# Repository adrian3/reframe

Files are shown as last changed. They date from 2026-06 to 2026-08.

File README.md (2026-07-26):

# reFrame – the ePaper camera

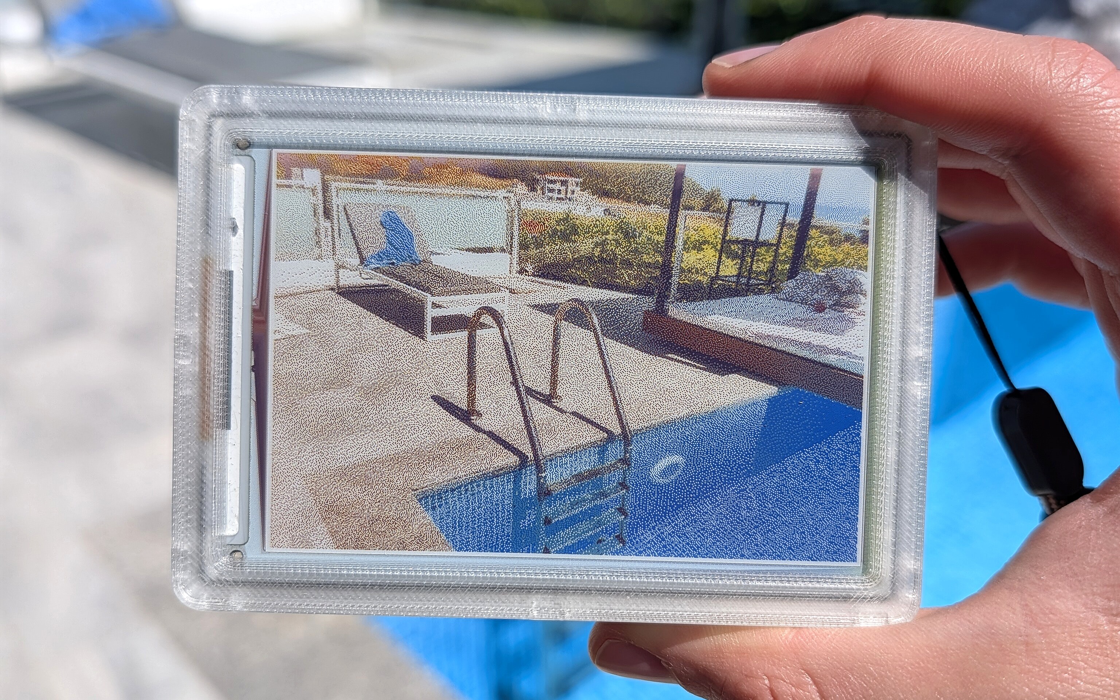
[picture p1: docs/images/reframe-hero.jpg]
reFrame ePaper camera in hand


reFrame is an experimental digital camera designed to capture and display one photo at a time.

reFrame uses a 6-color ePaper display, giving each photo a distinctive dithered texture. After you press the shutter, the display takes about 20 seconds to refresh — colors cycle through as electrical charges physically move ink particles into place, like a digital polaroid.

The photo stays on screen even after powering off. The only way to clear it is to take a new one. When not in use, reFrame doubles as a desk photo frame.

🌐 **[reframe.camera](https://reframe.camera)**

<p align="left">
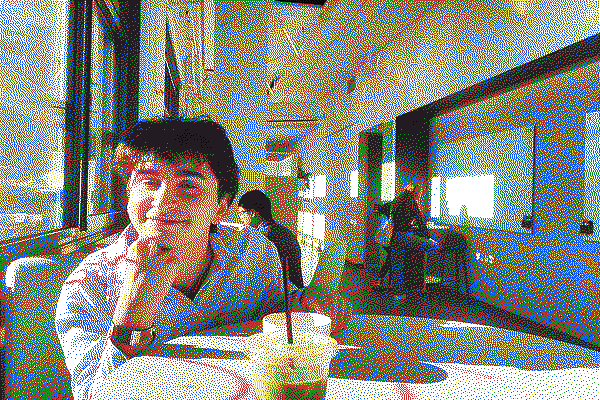
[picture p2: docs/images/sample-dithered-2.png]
Dithered photo sample
  
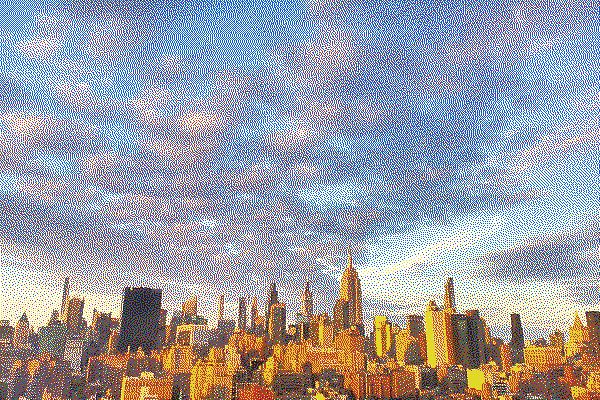
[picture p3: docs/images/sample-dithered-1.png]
Dithered photo sample
  
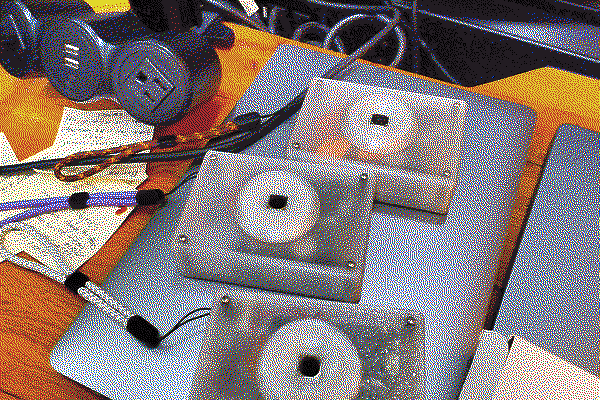
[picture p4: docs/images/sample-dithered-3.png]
Dithered photo sample
  
</p>

## What's Inside

The open source version of reFrame uses only off-the-shelf components so anyone can build their own.

| Component | Part |
|---|---|
| Computer | [Raspberry Pi Zero 2 W](https://www.pishop.us/product/raspberry-pi-zero-2w-with-headers/) |
| Camera | [Raspberry Pi Camera Module 3](https://www.digikey.com/en/products/detail/raspberry-pi/SC1223/17278639) |
| Display | [Waveshare 4" ePaper Spectra 6](https://www.waveshare.com/4inch-e-paper-hat-plus-e.htm) |
| Battery | [PiSugar 3](https://www.pisugar.com/products/pisugar-3-raspberry-pi-zero-battery) |
| Enclosure | 3D printed PLA |

See the full [bill of materials](docs/build-guide.md#materials).

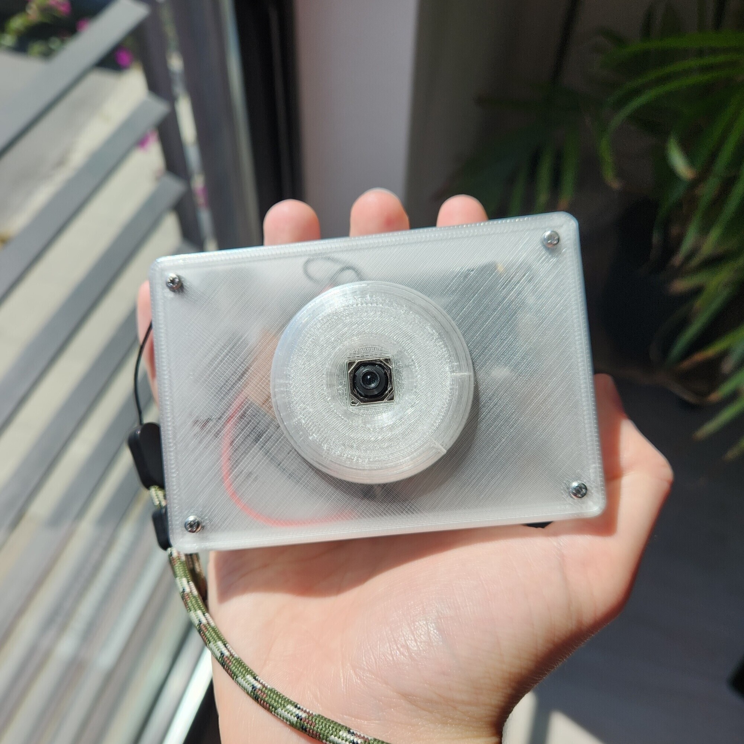
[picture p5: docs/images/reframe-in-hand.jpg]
reFrame ePaper camera in hand


## Getting Started

**→ [Build Guide](docs/build-guide.md)** — How to assemble the camera hardware

**→ [Software Setup](docs/software-setup.md)** — How to install and configure the software on your Pi

**→ [Hardware Porting Notes](docs/hardware-porting.md)** — How to adapt the code for other e-ink displays, cameras, or buttons

**→ [Dashboard Extensions](docs/dashboard-extensions.md)** — Upload your photos directly from the camera to Are.na + more.

Once you have the hardware assembled and Raspberry Pi OS flashed, run:

```bash
sudo apt update
sudo apt install -y git
git clone https://github.com/kaloyaan/reframe.git
cd reframe
chmod +x install.sh
./install.sh
```

## Using the Camera

  reFrame ePaper camera in action

reFrame is extremely minimalist by design. It has only a single button; no viewfinder, flash or zoom.

1. Press the combined power + shutter button to wake the camera and take a photo.
2. The original image is saved, then dithered to a 6-color palette to match the screen. The processed image is sent to the ePaper display.
3. The ePaper screen takes about 20 seconds to display the photo.
4. Press the button again to take a new photo. It'll replace the previous one on the display.
5. When you turn the camera off, the last photo will stay on the screen.

A web dashboard, accessible over the local network, lets you browse photos, download originals, change the displayed image, adjust camera settings, and optionally upload dithered photos to Are.na.

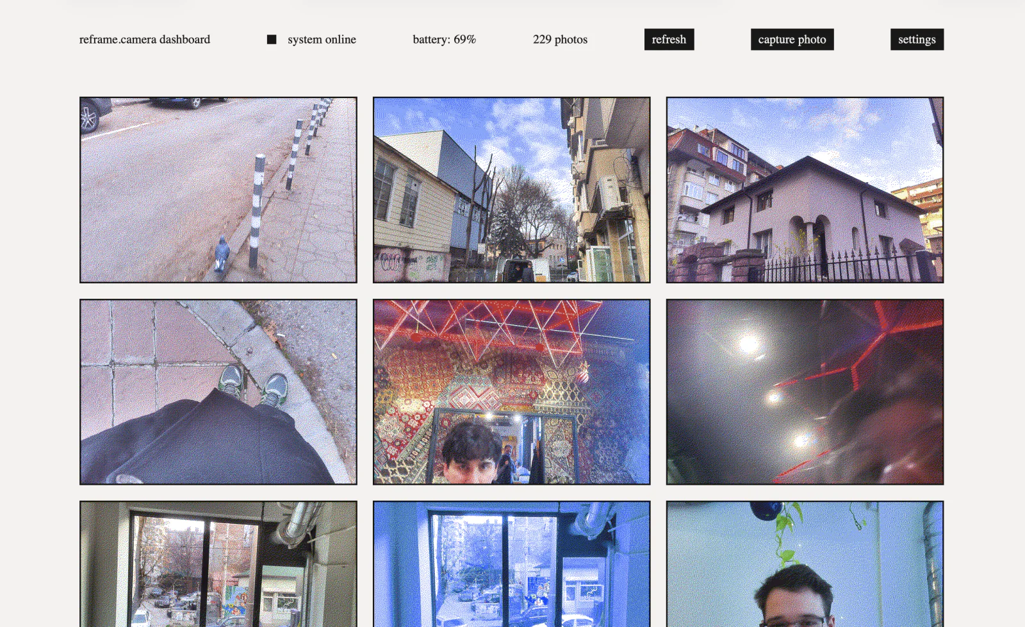
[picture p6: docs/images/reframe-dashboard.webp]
reFrame dashboard showing the photo gallery and camera controls


## Repository Structure

```
reframe/
├── reframe.py                 # main camera application
├── dashboard.py               # web dashboard for photo management
├── dashboard_proxy.py         # local port 80 dashboard proxy
├── install.sh                 # one-command setup script
├── settings.example.json      # default configuration
├── scripts/                   # hardware and privileged system helpers
│   ├── enable_hdr.sh
│   ├── reframe-apply-update
│   └── reframe-rtc-sync
├── systemd/                   # camera, dashboard, and RTC service units
│   ├── reframe.service
│   ├── reframe-dashboard.service
│   ├── reframe-dashboard-proxy.service
│   ├── reframe-rtc-restore.service
│   └── reframe-rtc-update.service
├── waveshare_epd/             # e-ink display drivers
├── hardware/                  # 3D-printable enclosure files
└── docs/                      # build guide & software setup
    ├── build-guide.md
    ├── software-setup.md
    ├── hardware-porting.md
    ├── dashboard-extensions.md
    └── images/
```

## License

Software in this repository is licensed under the [Apache License 2.0](LICENSE), unless a file says otherwise.

Hardware design files in [hardware/](hardware/) are licensed under [CC BY 4.0](hardware/LICENSE.md).

The build guide and documentation are provided for reuse with attribution where original to this project. Photos may include third-party products, packaging, logos, or trademarks, which are not licensed by this project.

The reFrame name, logo, domain, and branding are reserved.

## Credits

reFrame is made by [Kaloyan Kolev](https://kaloyankolev.com) with help from lots of friends and family. It started as a thesis prototype at Yale under the name eink.cam.

Thank you to [APOSSIBLE](https://apossible.com) for their generous support of this project.

reFrame logo + branding by [Kevin Chen](https://kevinnchen.com/).

More updates on [Instagram](https://instagram.com/reframe.camera).

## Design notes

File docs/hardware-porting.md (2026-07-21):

# Hardware Porting Notes

reFrame is intentionally small and mostly contained in `reframe.py`. If you want to use a different camera, display, or button, you can keep the same high-level logic and swap the hardware-specific adapter code.

## Display

The default display adapter is `EInkDisplay` in `reframe.py`, using the bundled Waveshare `epd4in0e` driver.

To port another e-ink display:

- Update `DISPLAY_IMAGE_WIDTH`, `DISPLAY_IMAGE_HEIGHT`, `DISPLAY_PANEL_WIDTH`, and `DISPLAY_PANEL_HEIGHT`.
- Update the palettes and hardware color mapping in `ImageProcessor`.
- Keep `EInkDisplay`'s public methods compatible: `prepare_async`, `is_busy`, `display_image`, `display_buffer`, `display_buffer_async`, `display_photo_by_id`, `clear_display`, `display_dashboard_qr`, and `sleep`.

You can find similar E Ink Spectra 6 displays from other brands like Pimoroni, GooDisplay, etc.

## Camera

The default camera adapter is `CameraManager`, backed by Picamera2 and Raspberry Pi Camera Module 3.

To port another camera:

- Keep `capture_image_with_metadata()` returning `(result_dict, PIL_image)`.
- Make `capture_image()` return a PIL `RGB` image.
- Keep `configure_camera()`, `reload_settings()`, and `apply_camera_settings()` present, even if some settings become no-ops.
- Update or remove `scripts/enable_hdr.sh` and the `_enable_camera_hdr()` startup call in `reframe.py` if your camera does not use Camera Module 3 HDR.
- Update `settings.example.json` camera defaults for the resolution and controls your camera supports.

## Button And Power

The default button path reads PiSugar 3 over I2C in `main()`. To port another trigger:

- Replace `is_power_button_pressed()` in `main()`.
- Keep the short-press behavior calling `camera_system.capture_photo_api()`.
- Keep long-press shutdown behavior in the power manager if your hardware has one; otherwise implement it explicitly.

## Dashboard

The dashboard talks to the hardware service through the API routes in `reframe.py`. If the adapter methods above remain compatible, the dashboard should not need display- or camera-specific changes.

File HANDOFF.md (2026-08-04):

# reFrame Camera — Setup Handoff

Context for picking up this project. The working repo is at `~/Desktop/reframe` (cloned from https://github.com/kaloyaan/reframe, now diverged from upstream — see changes below).

## Build deviation from stock instructions

This build powers the Raspberry Pi Zero 2 W directly (plain USB/battery power) instead of through a PiSugar 3 board. That removes PiSugar's hardware power-on, hardware long-press shutdown, and battery monitoring. To compensate, a physical momentary push button was wired directly to the Pi's GPIO for photo capture:

- Button leg 1 → **GPIO4** (physical pin 7 on the 40-pin header)
- Button leg 2 → **GND** (physical pin 9, adjacent to pin 7)
- No external resistor — code enables the Pi's internal pull-up, so idle = HIGH, pressed = LOW.

Optional shutdown warning buzzer:

- Buzzer `+` / signal → **GPIO23** (physical pin 16)
- Buzzer `-` / GND → **GND** (physical pin 14 is nearby)
- Current settings use the buzzer for a shutter click on capture, a warning one minute before the 10-minute inactivity shutdown, and a shutdown cadence before long-press or inactivity shutdown.
- Use a small active 3.3V buzzer or a low-current piezo. If the buzzer draws more than a few milliamps, drive it with a transistor instead of directly from the GPIO pin.

## Code changes already made (local repo, not pushed upstream)

**`reframe.py`** — in `main()`, the PiSugar I2C button-read block was replaced with a direct GPIO read:
- Removed: `smbus2` I2C read from PiSugar register `0x02` at address `0x57`.
- Added: `gpiozero.Button(4, pull_up=True, bounce_time=0.02)`, with `is_power_button_pressed()` now just returning `shutter_button.is_pressed`.
- The existing short-press (capture) / long-press (ignore) polling loop below it was untouched — it only calls `is_power_button_pressed()`, so no other logic needed to change.
- `finally: bus.close()` → `finally: shutter_button.close()`.
- `gpiozero` needed no new dependency — it's already used by `waveshare_epd/epdconfig.py` for the display, so it's present on the Pi already.

**`install.sh`** — Step 3 ("PiSugar Power Manager") was replaced with a no-op that just logs a warning and skips it, since there's no PiSugar hardware to detect. Everything else in the script (system packages, SPI/I2C enable via `raspi-config`, boot-speed trims, systemd services, user groups) is unmodified and still needed — SPI is still required for the e-ink display, and the `gpio` group (already added by `usermod` in the script) covers permission for GPIO4.

**Camera/display processing** — this build is currently configured for Raspberry Pi Camera Module V2 / NoIR V2 (`imx219`):
- Boot config should use `camera_auto_detect=0` and `dtoverlay=imx219`.
- Capture defaults are `3280×2464`, the full Camera Module V2 still resolution.
- Original JPEGs are saved at full capture resolution.
- The dithered display image keeps the full `2464px` source height, center-crops width to about `1643px`, resizes that portrait crop to `400×600`, then rotates it `-90°` to the final `600×400` dithered image. This loses more width than the previous landscape crop but preserves full height.

Nothing else in the codebase hard-depends on PiSugar: `dashboard.py`'s `/api/battery` endpoint calls `nc` to `127.0.0.1:8423` and gracefully returns `battery_level: None` if `pisugar-server` isn't running (dashboard just shows `--%`), and `reframe.service` has no `Requires=`/`After=` on `pisugar-server.service`.

## Current status

SD card is flashed (Raspberry Pi OS Lite, hostname `reframe`, user `cam`), the Pi is wired up with the camera, e-ink display, and the direct GPIO button, and it was booting for the first time as of this handoff. SSH has not yet been used to install the software on the Pi itself — the local repo on the Mac has the code changes above, but that code has not yet been transferred to the Pi.

## Remaining steps

Run from the user's own Mac terminal (an assistant needs actual local-network/SSH access to the Pi to do this — a sandboxed environment without LAN access cannot reach `reframe.local`):

```bash
# 1. SSH in (password is whatever was set in Raspberry Pi Imager)
ssh cam@reframe.local

# 2. From a separate terminal window (not the SSH session), copy the
#    locally-modified repo to the Pi — do NOT git clone from GitHub,
#    that would pull the vanilla version without the GPIO button change
rsync -av --exclude='.git' ~/Desktop/reframe/ cam@reframe.local:~/reframe/

# 3. Back in the SSH session, install
cd ~/reframe
chmod +x install.sh
./install.sh
# It will print that it's skipping PiSugar, then proceed normally.
# Say yes when it prompts to reboot.
```

After reboot, verify:

```bash
# Watch for capture events while pressing the button
sudo journalctl -u reframe.service -f
# Should log "Short press detected... capturing photo" on press

# If the button seems unresponsive, sanity-check the pin directly
python3 -c "from gpiozero import Button; b=Button(4); print('press now...'); [print(b.is_pressed) for _ in range(100)]"
# Should print True while held
```

Dashboard: `http://reframe.local` (fallback `http://reframe.local:8000`). Battery will show `--%` since there's no PiSugar — expected.

## WiFi priority

The live Pi is using NetworkManager. It has two WiFi profiles:

- `iphone-hotspot` — SSID `Ade’s iPhone 17 Pro`, autoconnect priority `100`
- `netplan-wlan0-Area53` — home WiFi fallback, autoconnect priority `10`

The hotspot password is stored only in NetworkManager on the Pi, not in this repo. A boot helper, `reframe-prefer-phone-wifi.service`, scans for several minutes after networking starts and switches to `iphone-hotspot` if the phone SSID is visible; otherwise it leaves Area53 or any other current connection alone.

On a fresh SD card, add the phone network with:

```bash
sudo nmcli connection add type wifi ifname wlan0 con-name iphone-hotspot ssid "Ade’s iPhone 17 Pro"
sudo nmcli connection modify iphone-hotspot \
  connection.autoconnect yes \
  connection.autoconnect-priority 100 \
  connection.autoconnect-retries -1 \
  wifi-sec.key-mgmt wpa-psk \
  wifi-sec.psk "<iphone hotspot password>"
sudo nmcli connection modify netplan-wlan0-Area53 \
  connection.autoconnect yes \
  connection.autoconnect-priority 10 \
  connection.autoconnect-retries -1
sudo systemctl enable reframe-prefer-phone-wifi.service
```

On the iPhone, keep **Personal Hotspot → Allow Others to Join** enabled when using the camera outside. If the Pi does not see the hotspot, enable **Maximize Compatibility** so the hotspot is available in a Pi Zero-friendly 2.4 GHz mode.

If the Pi still does not see the hotspot, unlock the iPhone and leave **Settings → Personal Hotspot** open while powering on the camera. iPhones sometimes stop advertising the hotspot aggressively when no device is connected.

## Known non-issue

Long-press-to-shutdown is implemented in software: hold the GPIO4 shutter button for at least 2 seconds, release, and reFrame plays the shutdown cadence on GPIO23 before running `sudo shutdown -h now`. The 10-minute inactivity auto-shutdown also remains enabled. After shutdown, powering the camera back on still means unplugging/replugging power because this direct-power build has no PiSugar-style hardware wake circuit.

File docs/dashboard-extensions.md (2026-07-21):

# Dashboard Upload Extensions

Dashboard extensions add extra per-photo action buttons in the web dashboard. They are server-side only, off by default, and configured through `settings.json` via the dashboard settings modal.

The first built-in extension is photo upload to an [Are.na](https://www.are.na/) channel.

## How Extensions Work

Extensions live in `dashboard.py` and are registered in `extension_registry`.

Each extension should provide:

- `id`: stable machine id used in settings and API paths
- `label`: human-readable name
- `action_label`: text shown on the photo action button
- `requires_dithered`: whether the action should only appear for photos with a dithered file
- `enabled(settings)`: whether the extension is enabled
- `configured(settings)`: whether all required settings are present
- `run(photo, settings)`: async server-side action

The browser doesn't receive secrets, it only asks:

```http
GET /api/extensions/actions
```

That returns safe action metadata for configured extensions. When a user taps an extension button, the dashboard calls:

```http
POST /api/extensions/{extension_id}/photos/{photo_id}
```

The dashboard server loads the photo metadata, reads private settings, and runs the extension.

For v1, extensions are not loaded dynamically from arbitrary folders. To add one, subclass `DashboardExtension` in `dashboard.py` and register it in `ExtensionRegistry([...])`.

## Settings Shape

Extension settings are stored under `extensions`:

```json
{
  "extensions": {
    "arena": {
      "enabled": false,
      "channel": "",
      "access_token": ""
    }
  }
}
```

Tokens are write-only in the dashboard API:

- `GET /api/settings` returns `access_token: ""`
- `GET /api/settings` also returns `access_token_configured: true` when a saved token exists
- saving settings with a blank token preserves the saved token
- entering a new token replaces the saved token
- using the clear-token control sets `access_token_clear: true` and removes the saved token

This avoids accidentally exposing tokens to the browser UI, but the dashboard is still trusted-LAN software. Do not expose it directly to the public internet.

## Are.na Upload

The Are.na extension uploads the dithered PNG version of a photo to a configured Are.na channel.

Example Are.na channel: [Shot on reFrame](https://www.are.na/kalo/shot-on-reframe).

### Setup

1. Create an Are.na channel.
2. Create an Are.na API access token with write access.
3. Open the reFrame dashboard.
4. Open settings.
5. Under `extensions`, set `are.na upload` to `enabled`.
6. Enter the channel slug or numeric id.
7. Paste the access token and save settings.

When the extension is fully configured, an `are.na` button appears next to photo actions for photos that have a dithered PNG.

### What Gets Uploaded

Only the dithered PNG is uploaded. Original JPEGs are not uploaded by this extension.

If the advanced 2× dithered export setting is enabled, the dashboard enlarges the PNG with nearest-neighbor scaling immediately before upload. It does not crop or modify the stored dithered photo. The setting is disabled by default.

The created Are.na block uses:

- title: `reFrame {photo_id}`
- description:

```text
Dithered photo shot on [reframe.camera](https://reframe.camera)

Captured on {timestamp}
```

If `system.camera_name` is set in dashboard settings, the captured line appends `by {camera_name}`.

- metadata:

```json
{
  "source": "reframe",
  "photo_id": "{photo_id}"
}
```

## Adding Another Extension

Add a new class in `dashboard.py`:

```python
class ExampleExtension(DashboardExtension):
    id = "example"
    label = "Example"
    action_label = "example"
    requires_dithered = True

    def configured(self, settings):
        extension_settings = self.get_settings(settings)
        return self.enabled(settings) and bool(extension_settings.get("api_key"))

    async def run(self, photo, settings):
        dithered_path = photo.get("dithered_path")
        if not dithered_path:
            raise HTTPException(status_code=400, detail="This photo does not have a dithered version")
        # Upload or process the file here.
        return {
            "status": "success",
            "message": "Uploaded photo",
            "extension": self.id
        }
```

Then register it:

```python
extension_registry = ExtensionRegistry([
    ArenaExtension(),
    ExampleExtension(),
])
```

Add its settings defaults to `SettingsManager.default_settings`, `settings.example.json`, and the dashboard settings UI. If the extension has a secret, mirror the Are.na write-only token behavior.

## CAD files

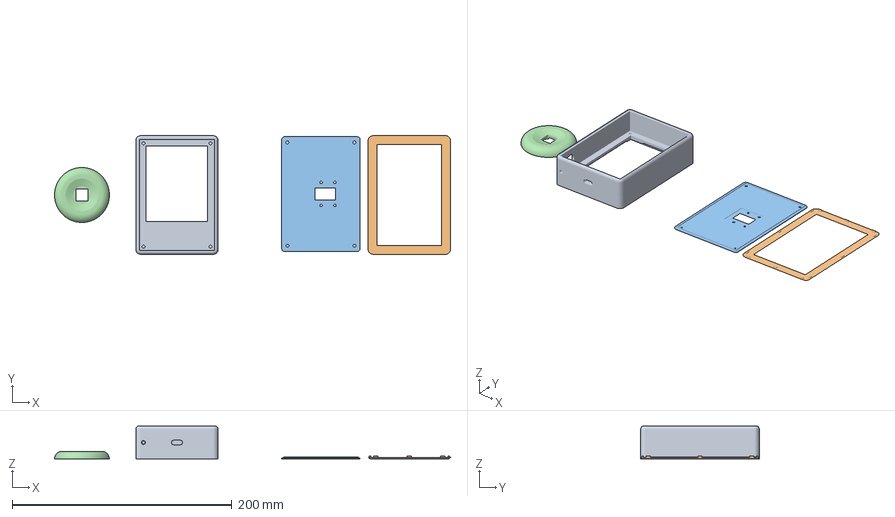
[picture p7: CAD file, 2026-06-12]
hardware/reframe-3dprint.3mf
360.5 x 108.0 x 30.0 mm
enclosure 10.stl
bezel 8.stl
lid 8.stl
ring 9.stl

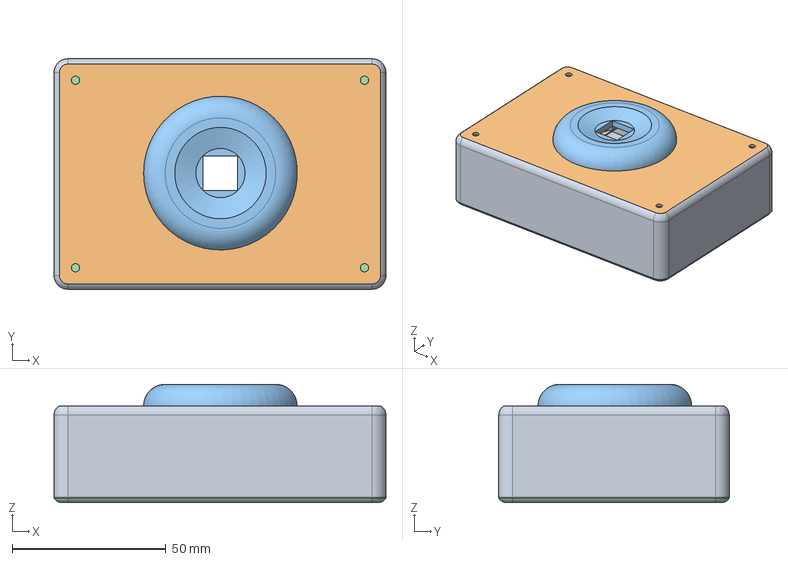
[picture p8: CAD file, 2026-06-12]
hardware/reframe.step
108.0 x 75.0 x 38.5 mm

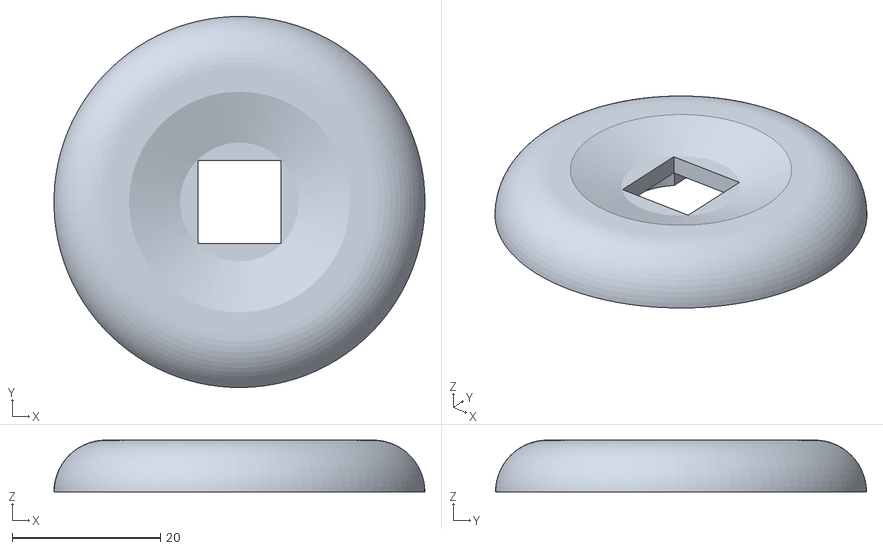
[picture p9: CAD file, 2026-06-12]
hardware/ring.stl
50.0 x 50.0 x 7.00

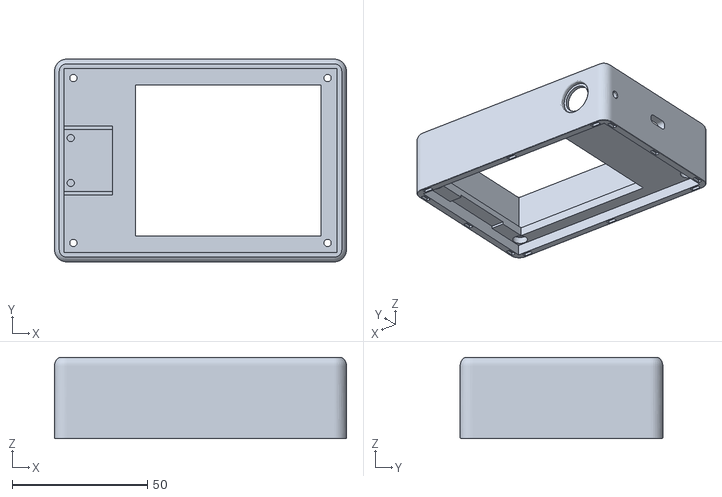
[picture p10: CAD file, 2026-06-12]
hardware/enclosure.stl
108.0 x 75.0 x 30.0

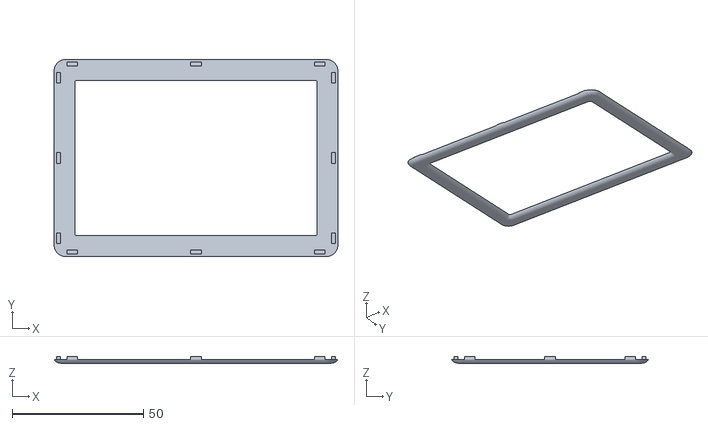
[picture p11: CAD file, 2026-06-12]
hardware/bezel.stl
108.0 x 75.0 x 2.50

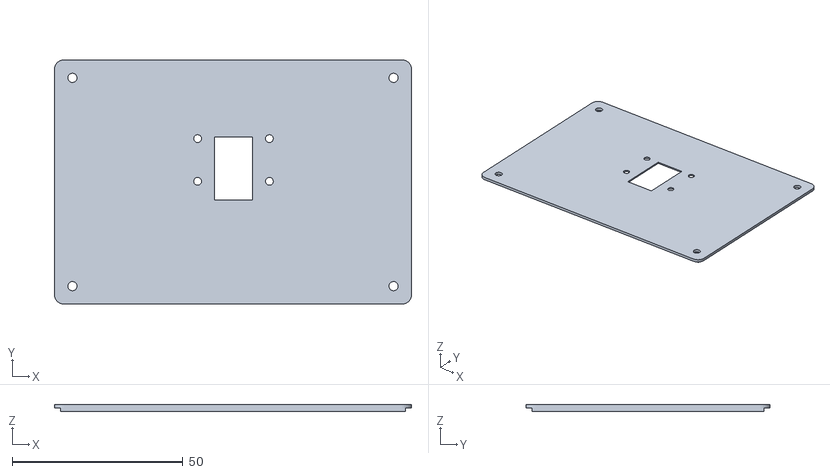
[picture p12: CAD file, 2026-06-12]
hardware/lid.stl
104.5 x 71.5 x 2.00

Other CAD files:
hardware/reframe.f3d

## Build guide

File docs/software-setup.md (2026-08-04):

# Software Setup

How to set up a reFrame camera from scratch.

## 1. Flash the SD Card

Download and install [Raspberry Pi Imager](https://www.raspberrypi.com/software/). Insert a microSD card into your computer and flash it with the following settings:

- **Device**: Raspberry Pi Zero 2 W
- **OS:** Raspberry Pi OS (other) > Raspberry Pi OS Lite (64-bit)
- **Hostname:** `reframe`
- **Username:** `cam`
- **Password:** your choice (but write it down somewhere safe)
- **WiFi:** enter your home network name and password. If you want to use the camera on the go, also add your phone's hotspot (you can add multiple networks)
- **Services:** Enable SSH with password authentication

Eject the card, insert it into the Pi Zero 2 W, and power it on. On a new
PiSugar 3, the first power-on may require a short press followed by a long
press. The reFrame installer disables this accidental-touch prevention mode so
later power-ons use a single press.

## 2. SSH into the Pi

Once the Pi has booted (give it a minute), connect from your computer:

```bash
ssh cam@reframe.local
```

Enter the password you set in the imager.

## 3. Install reFrame

```bash
sudo apt update
sudo apt install -y git
git clone https://github.com/kaloyaan/reframe.git
cd reframe
chmod +x install.sh
./install.sh
```

If the official PiSugar installer asks you to select a model, choose **PiSugar 3**. After installation:

- `pisugar-server` runs as a systemd service and starts on boot
- Battery level is available via TCP on port `8423` (the dashboard reads this automatically)
- Power management web UI is at `http://reframe.local:8421`

By default, PiSugar 3 ships with accidental-touch prevention enabled. In that mode, power-on requires a short press followed by a long press. reFrame disables that mode during installation so the camera behaves like this:

- **single press while off** = power on
- **startup** = automatically take and display one photo
- **single press while on** = take a new photo
- **long press while on** = shut down
- **10 minutes of inactivity** = automatic shutdown to prevent battery drain

The installer applies this with the PiSugar Power Manager command `set_anti_mistouch false`. If you installed PiSugar after running `install.sh`, run the reFrame installer again, or apply the setting manually:

```bash
echo "set_anti_mistouch false" | nc -q 0 127.0.0.1 8423
```

You can check the current setting with:

```bash
echo "get anti_mistouch" | nc -q 0 127.0.0.1 8423
```

> **Note:** reFrame reads the button directly via I2C (address `0x57`) for photo capture. PiSugar still handles battery monitoring, one-press power-on, and long-press shutdown.

### PiSugar RTC

The installer keeps the Raspberry Pi system clock and the PiSugar 3 real-time clock in UTC. reFrame synchronizes them automatically on startup: it syncs the system clock from the RTC, and whenever network time becomes available it updates both clocks.

## 4. Reboot

```bash
sudo reboot
```

After rebooting, reFrame starts automatically. The camera takes a photo on startup, sends it to the ePaper screen, then saves the original JPEG and dithered PNG in the background.

### Troubleshooting / Verifying the Installation

If something is not working, SSH back into the camera after it finishes booting, then check that all three services are active:

```bash
sudo systemctl is-active \
    reframe.service \
    reframe-dashboard.service \
    reframe-dashboard-proxy.service
```

Each line should say `active`. Confirm that the services select the managed
Python environment:

```bash
/home/cam/reframe/scripts/reframe-python -c \
    'import sys; print(sys.executable)'
```

The result should be `/home/cam/reframe/.venv/bin/python`. Finally, test both
dashboard paths from the camera itself:

```bash
wget -q --spider http://127.0.0.1:8000/ && echo "dashboard backend OK"
wget -q --spider http://127.0.0.1/ && echo "dashboard proxy OK"
```

---

## Dashboard

reFrame dashboard showing the photo gallery and camera controls

Open a browser on any device connected to the same network:

```
http://reframe.local
```

The dashboard lets you browse photos, download originals, change the displayed image, and adjust camera settings.

The dashboard also remains available on port 8000 as a fallback:

```
http://reframe.local:8000
```

If you used a different Pi hostname during Raspberry Pi Imager setup, replace `reframe` with that hostname.

Dashboard settings include a software update button for git-based installs. It checks the configured upstream repo, installs fast-forward updates only, preserves ignored user data such as your settings and photos, refreshes dependencies and service files, and asks you to reboot after a successful update.

Advanced export settings include an optional 2× dithered-image mode. When enabled, dithered downloads and Are.na uploads are enlarged at export time to help them look sharp on social media. Original photos, stored dithered photos, gallery previews, display output, and download-all ZIP files are unchanged. This option is disabled by default.

### Using with a Phone Hotspot

To use the camera without a WiFi network, enable your phone's hotspot. As long as you added the hotspot name and password during flashing (step 1), the Pi will connect to it automatically on boot.

On iPhone, you can find your hotspot name under Settings → General → About → Name. Enable **Maximize Compatibility** in hotspot settings for the Pi to connect reliably.

Whenever the camera connects or reconnects to WiFi, it shows a dashboard QR code on the ePaper display. The network watcher remains active after startup, and the QR encodes the numeric IP when one is available so it also works on hotspots that do not resolve `.local` hostnames. This behavior is enabled by default and can be disabled under system settings in the dashboard.

On Android/Pixel hotspots, `.local` hostnames may not resolve reliably. In that case, use the QR code's numeric IP URL, for example `http://192.168.x.x`.

## HDR (Camera Module 3)

HDR is automatically enabled at startup via `scripts/enable_hdr.sh` after Python imports finish but before Picamera2 opens the camera. This overlaps camera-device discovery with Python startup. To control it manually:

```bash
# Enable
v4l2-ctl --set-ctrl wide_dynamic_range=1 -d /dev/v4l-subdev0

# Disable
v4l2-ctl --set-ctrl wide_dynamic_range=0 -d /dev/v4l-subdev0
```

HDR + autofocus make a big difference on the ePaper display.

## Photo Formats And Capture Flow

reFrame captures the startup/button photo into memory first so the image can be dithered and sent to the ePaper display quickly. It then saves files in the background:

- Original camera captures are saved as JPEGs at the configured camera resolution. For the local Camera Module V2 build, the default is the full `3280×2464` still frame.
- The display/dashboard dithered version is saved as a `600×400` PNG so the 6-color dithered image stays crisp.
- To make the `3280×2464` camera frame fit the display without distortion, reFrame keeps the full `2464px` source height, center-crops width to about `1643px`, resizes that portrait crop to `400×600`, then rotates it `-90°` to the final `600×400` dithered image.
- Immediately after a capture, the dashboard may take a moment to show the newest files while the background save finishes.

By default, reFrame shuts down automatically after 10 minutes without button, dashboard, or display activity to avoid draining the PiSugar battery. You can change this in `settings.json` with `system.auto_timeout_minutes` and `system.auto_timeout_enabled`.

## Other Displays Or Cameras

The reference build uses Raspberry Pi Camera Module 3, PiSugar 3, and a Waveshare 4" Spectra 6 ePaper HAT, but the hardware-specific code is intentionally isolated in `CameraManager`, `EInkDisplay`, and the small button block in `reframe.py`.

See [Hardware Porting Notes](hardware-porting.md) for adapting the repo for Pimoroni, Good Display, another camera module, or a different button/power board.

## Upload Extensions

The dashboard can show optional per-photo upload buttons. Extensions are off by default and run on the dashboard server so API tokens are not sent back to the browser.

The built-in Are.na extension uploads the dithered PNG of a photo. Enable it from dashboard settings by entering an Are.na channel slug/id and an access token with write access. The token field is write-only: leave it blank to keep the saved token, enter a new token to replace it, or use the clear-token button to remove it.

Example Are.na channel: [Shot on reFrame](https://www.are.na/kalo/shot-on-reframe).

See [Dashboard Extensions](dashboard-extensions.md) for the full Are.na flow and notes on adding your own upload extension.

## Service Commands

```bash
sudo systemctl status reframe.service      # check status
sudo journalctl -u reframe.service -f      # view logs
sudo systemctl restart reframe.service     # restart
sudo systemctl stop reframe.service        # stop

sudo systemctl status reframe-dashboard.service       # dashboard backend
sudo journalctl -u reframe-dashboard.service -f       # dashboard logs
sudo systemctl restart reframe-dashboard.service      # restart dashboard
```

---

## Manual Install

If you prefer to set things up by hand, here's what the install script does:

### System Packages

```bash
sudo apt update
sudo apt install -y git python3-pip python3-venv python3-picamera2 python3-spidev \
    python3-gpiozero v4l-utils i2c-tools netcat-openbsd wget
```

### PiSugar Power Manager

```bash
wget https://cdn.pisugar.com/release/pisugar-power-manager.sh
bash pisugar-power-manager.sh -c release
echo "set_anti_mistouch false" | nc -q 0 127.0.0.1 8423
```

Select **PiSugar 3** if prompted by the PiSugar installer.

### Python Packages

```bash
python3 -m venv --system-site-packages .venv
PYTHONNOUSERSITE=1 .venv/bin/python -m pip install -r requirements.txt
```

`--system-site-packages` makes the Raspberry Pi OS Picamera2/libcamera packages
available inside the project environment. `PYTHONNOUSERSITE=1` keeps the
environment reproducible if setup is rerun or the camera is upgraded by
preventing unrelated packages in `~/.local` from taking precedence. A fresh
installation does not need any special cleanup. Do not delete the operating
system's `EXTERNALLY-MANAGED` marker or globally enable
`--break-system-packages`.

### Enable Hardware Interfaces

```bash
sudo raspi-config nonint do_i2c 0
sudo raspi-config nonint do_spi 0
```

This local build is configured for the Raspberry Pi Camera Module V2 / NoIR V2
(`imx219`). Use this boot config:

```bash
camera_auto_detect=0
dtoverlay=imx219
```

Boot config paths:
- **Bullseye:** `/boot/config.txt`
- **Bookworm:** `/boot/firmware/config.txt`

### User Permissions

```bash
sudo usermod -a -G video,i2c,spi,gpio cam
```

Log out and back in for changes to take effect.

### Configuration

```bash
cp settings.example.json settings.json
```

### Systemd Services

```bash
sudo cp systemd/reframe.service /etc/systemd/system/
sudo cp systemd/reframe-dashboard.service /etc/systemd/system/
sudo cp systemd/reframe-dashboard-proxy.service /etc/systemd/system/
sudo cp systemd/reframe-rtc-restore.service /etc/systemd/system/
sudo cp systemd/reframe-rtc-update.service /etc/systemd/system/
chmod +x scripts/enable_hdr.sh scripts/reframe-python
sudo install -o root -g root -m 0755 scripts/reframe-rtc-sync /usr/local/sbin/reframe-rtc-sync
sudo install -d -o root -g root -m 0755 /var/lib/reframe
sudo timedatectl set-timezone UTC
sudo timedatectl set-ntp true
sudo systemctl daemon-reload
sudo systemctl reenable reframe.service
sudo systemctl enable reframe-dashboard.service reframe-dashboard-proxy.service reframe-rtc-restore.service reframe-rtc-update.service
sudo reboot
```

### Boot-Speed Settings

The camera service selects the `ondemand` CPU governor when the host supports it. This lets capture and image processing use the Pi's full clock under load while returning to its lower idle clock between photos.

The installer optimizes for fastest boot-to-first-photo while keeping WiFi, SSH, mDNS, PiSugar, and camera capture working.

It writes these headless hardware settings to the Pi boot config.

```bash
dtoverlay=disable-bt
dtparam=audio=off
hdmi_blanking=2
boot_delay=0
camera_auto_detect=0
dtoverlay=imx219
display_auto_detect=0
disable_splash=1
disable_poe_fan=1
force_eeprom_read=0
enable_tvout=0
```

It also disables services and timers that are not needed for a headless camera:

```bash
sudo systemctl disable --now \
  ModemManager.service \
  triggerhappy.service triggerhappy.socket \
  udisks2.service rsync.service rpi-eeprom-update.service \
  networking.service keyboard-setup.service console-setup.service \
  rsyslog.service \
  bluetooth.service hciuart.service bluealsa.service \
  apt-daily.timer apt-daily-upgrade.timer man-db.timer \
  e2scrub_all.timer fstrim.timer
```

Do **not** disable these for the normal camera build:

```bash
ssh.service
wpa_supplicant.service
dhcpcd.service
avahi-daemon.service
pisugar-server.service
reframe.service
reframe-dashboard.service
reframe-dashboard-proxy.service
```

On the reference Pi Zero 2 W, these changes plus the in-memory capture path reduced app-level startup capture-to-display dispatch to under 1 second once Picamera2 is ready. A cold boot still includes OS, HDR, Python import, and libcamera startup time; the ePaper display refresh itself still takes about 20 seconds to physically finish, and that is expected.

To undo the service trims, re-enable only what you need, for example:

```bash
sudo systemctl enable --now bluetooth.service hciuart.service
```

---

## Troubleshooting

**Camera not detected**
- Verify the ribbon cable is seated properly on both ends
- Ensure `cam` is in the `video` group: `groups cam`

**Display not updating**
- Confirm SPI is enabled: `sudo raspi-config nonint get_spi` (should return `0`)
- Check physical connections between the display HAT and Pi header
- Review logs: `sudo journalctl -u reframe.service`

**Button not responding**
- Confirm I2C is enabled: `sudo raspi-config nonint get_i2c` (should return `0`)
- Check: `sudo i2cdetect -y 1` (should show a device at address `57` for PiSugar)

**Service won't start**
- The service files expect the repo at `/home/cam/reframe`
- Check: `sudo systemctl status reframe.service`
- View full logs: `sudo journalctl -u reframe.service --no-pager`

**Dashboard says it is starting or unavailable**
- Check the backend directly: `wget -S -O /dev/null http://127.0.0.1:8000/`
- Check its status: `sudo systemctl status reframe-dashboard.service --no-pager -l`
- View this boot's logs: `sudo journalctl -u reframe-dashboard.service -b --no-pager -n 100`
- Confirm the service interpreter exists: `test -x /home/cam/reframe/.venv/bin/python && echo OK`
- Re-run `./install.sh` if the virtual environment or dependencies are missing

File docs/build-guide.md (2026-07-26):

# Build Guide

Everything you need to build your own reFrame camera. This version intentionally uses only off-the-shelf components so it's easy to customize.

The build requires some 3D printing and soldering experience, so it's not necessarily for absolute beginners. If you need help with any part of the process, you can reach out via email or Instagram.

## Materials

Approximate cost: **~$200-250 USD per camera**

| # | Component | Part | ~Price | Link | Notes |
|---|---|---|---|---|---|
| 1 | Computer | Raspberry Pi Zero 2 WH | $20 | [PiShop.us](https://www.pishop.us/product/raspberry-pi-zero-2w-with-headers/) | WH version has pre-soldered headers for easier assembly. Non-header version works as well. |
| 2 | Camera | Raspberry Pi Camera Module 3 | $25 | [Digi-Key](https://www.digikey.com/en/products/detail/raspberry-pi/SC1223/17278639) | Standard field-of-view model. The Camera Module 3 is recommended because the autofocus and HDR make a big difference in image quality on the ePaper display. |
| 3 | Display | Waveshare 4" ePaper Spectra 6 (HAT+) | $50 | [Waveshare](https://www.waveshare.com/4inch-e-paper-hat-plus-e.htm?sku=27367) | Connects directly to the Pi's GPIO header — no additional wiring needed. The [driver](../waveshare_epd/) is bundled in this repo. |
| 4 | Battery | PiSugar 3 Battery Board | $40 | [PiSugar](https://www.pisugar.com/products/pisugar-3-raspberry-pi-zero-battery) or [Amazon](https://www.amazon.com/dp/B0FB3N1YSK) | Provides power and physical button interface. This build works only with PiSugar 3 because of how it handles on-off buttons. Requires [`pisugar-server`](https://github.com/PiSugar/PiSugar/wiki/PiSugar-Power-Manager-(Software)) for monitoring; the [Software Setup](software-setup.md) guide installs it. |
| 5 | Storage | 32 GB microSD card | $10 | Any brand, the faster, the better. | For OS and photo storage. |
| 6 | Push Button | 12mm Stainless Steel Push Button | $6 | [Amazon](https://www.amazon.com/dp/B0811QKG1R) | Used as a combined hardware on/off + shutter button. |
| 7 | Camera Cable | Short Pi ribbon cable | $6 | [Amazon](https://www.amazon.com/dp/B085RW9K13?th=1) | For neatness; can also use the one that comes with the camera. |
| 8 | Nylon Standoffs | M2.5 Hex Standoff Spacers Kit | $10 | [Amazon](https://www.amazon.com/COMRUN-M2-5-Standoff-Assortment-Motherboard/dp/B0CKBWQSNY/) | Hold the build together. The camera needs 4 20mm standofs; could be nylon or metal. |
| 9 | Metal Screws | M2.5 metal screws | $10 | [Amazon](https://www.amazon.com/dp/B01N5RDAUX) | Holds the front lid + the USB-C board. Could be metal or nylon (if you want to use the ones from the link above). I went with metal for a nicer look on the front lid.  |
| 10 | Camera Screws | M2 screws | $7 | [Amazon](https://www.amazon.com/QOOSIKICC-Assortment-Washers-Machine-Assorted/dp/B0DDY2L533/) | For mounting the camera module to the enclosure. |
| 11 | USB C Port | USB C Breakout Board | $8 | [Amazon](https://www.amazon.com/Breakout-Connector-Serial-Female-Adapter/dp/B0F2S1K5X8) | Used for external USB-C port access. |
| 12 | Connectors | JST 1.25mm 2-Pin Micro Connectors | $7 | [Amazon](https://www.amazon.com/dp/B013JRWCBU) | So it's easier to connect the USB-C port + power button during assembly. |
| 13 | Filament | Transparent PLA Filament | $20 | [Amazon](https://www.amazon.com/dp/B08VRM8KZJ) | Good for reliable overhangs and fine details (PETG could also work but is more finicky). Translucent so status lights are visible under the board. The one used in my build is the GIANTARM Clear PLA Filament. |
| 14 | Wrist Strap | Wrist strap | $6 | [Amazon](https://www.amazon.com/dp/B0BC8G4ZR2) | Hand strap for carrying. |
| 15 | Putty | Sticky putty | $4 | Any brand | For holding the battery securely in place. |
| 16 | Carry Case | Optional carry case | $12 | [Amazon](https://www.amazon.com/dp/B0DBLMKYGB) | For travel protection. This size (5.5" × 3.7" × 2.8") fits the camera well. |
| 17 | Charging Cable | USB-A to USB-C | - | - | For charging the camera. C-to-C cables might not work unless you solder some extra ports on the USB-C board. |

## Enclosure

The 3D-printable files for the camera case are located in the [hardware/](../hardware/) directory. The model consists of four separate parts:

- **[enclosure.stl](../hardware/enclosure.stl)**: The main body that holds the Pi, battery, and display. It has cutouts for the display, the USB-C port, the power/shutter button, and the wrist strap.
- **[lid.stl](../hardware/lid.stl)**: The back cover of the camera. It attaches to the main enclosure using 4x M2.5 screws that screw into the standoffs integrated into the main enclosure.
- **[bezel.stl](../hardware/bezel.stl)**: The front bezel that frames the ePaper display. It attaches to the notches of the enclosure.
- **[ring.stl](../hardware/ring.stl)**: The accent ring that protects the camera lens.

For modification or custom adjustments, you can also download:
- **[reframe.f3d](../hardware/reframe.f3d)**: The Fusion 360 CAD source file.
- **[reframe.step](../hardware/reframe.step)**: The STEP file for use in other CAD software.

If you're using BambuStudio as your slicer:
- **[reframe-3dprint.3mf](../hardware/reframe-3dprint.3mf)**: A pre-configured BambuLab project file containing all parts and settings.

### Slicer Settings

For optimal printing, use the following slicer settings:

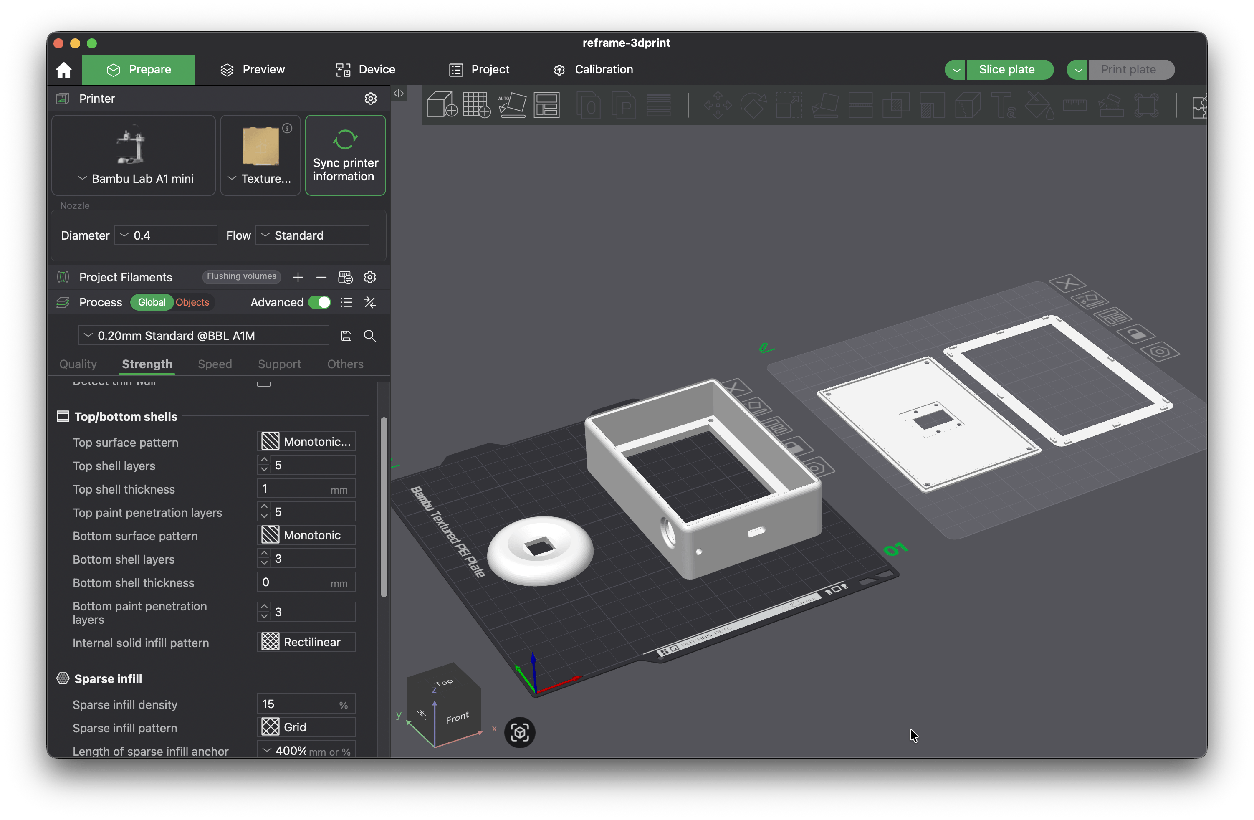
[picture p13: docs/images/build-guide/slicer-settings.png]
Slicer Layout

*Recommended print layout and orientation for all four components*

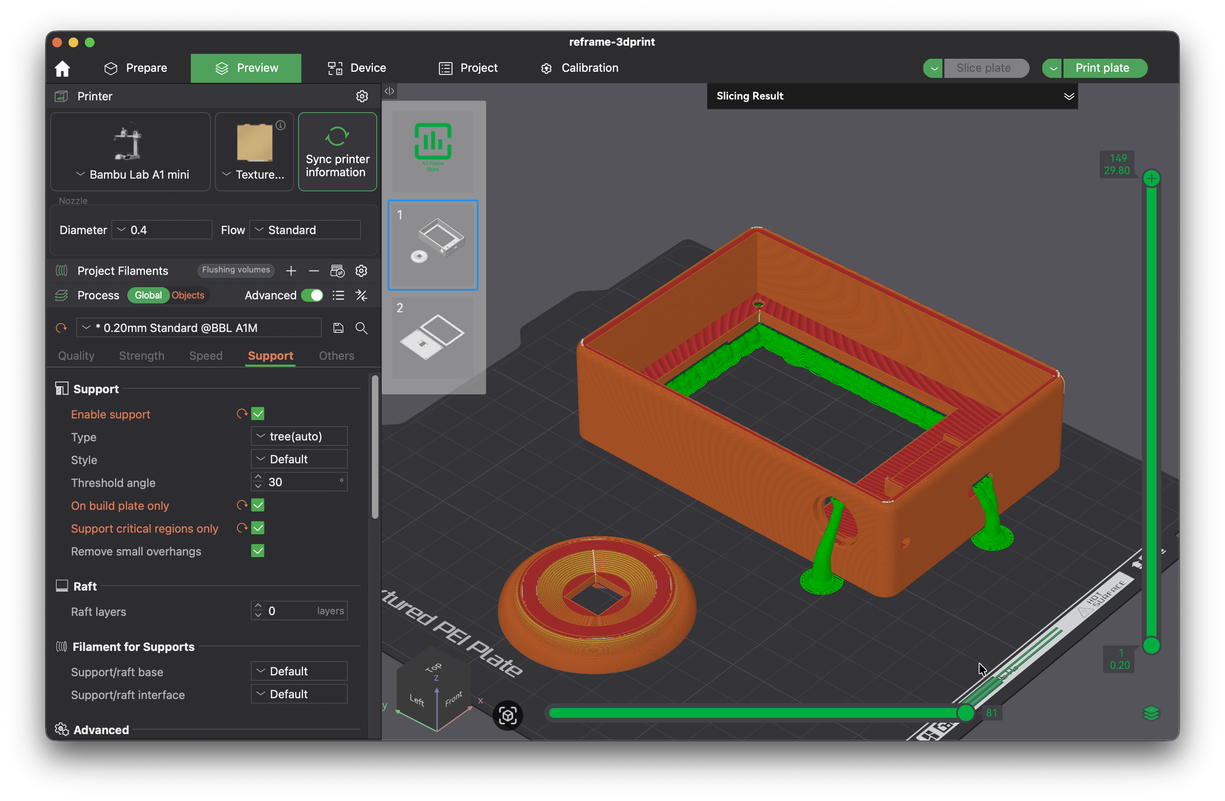
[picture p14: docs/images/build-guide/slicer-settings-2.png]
Slicer Parameters

*Supports needed for the overhangs of the enclosure.*

## 3D Printed Parts & Tools

Before starting assembly, make sure you have printed all the necessary enclosure parts and gathered the required tools.

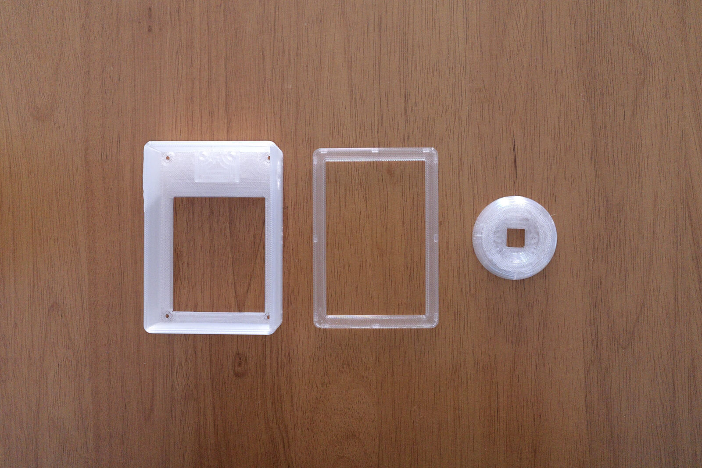
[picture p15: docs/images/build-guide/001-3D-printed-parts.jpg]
3D Printed Parts

*The 3D printed parts needed for the enclosure, printed in transparent PLA – missing here is the front panel.*

### Helpful Tools

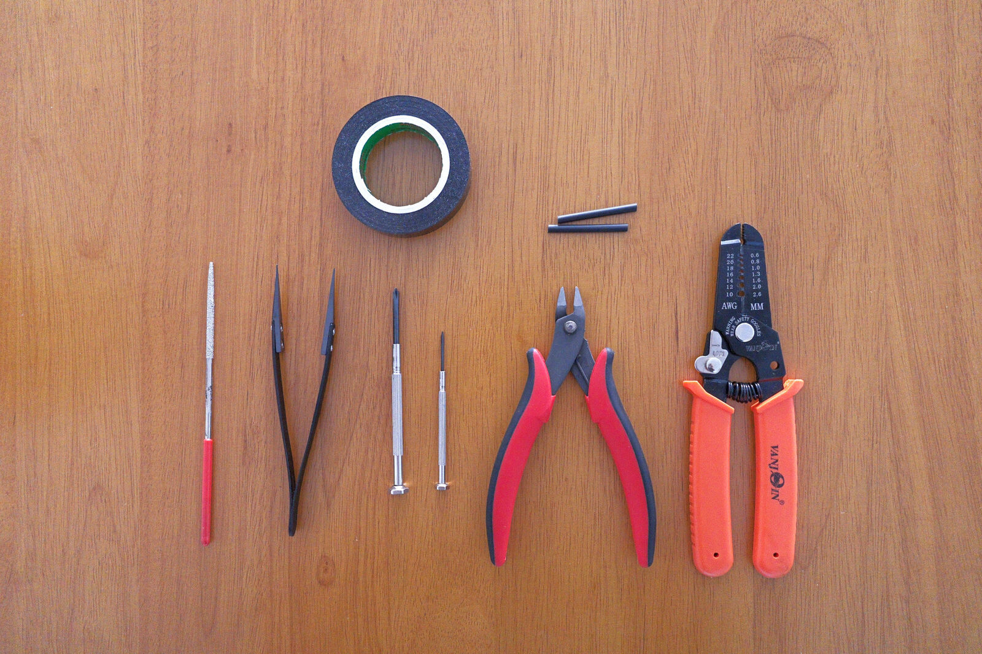
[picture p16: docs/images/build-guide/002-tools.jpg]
Tools Needed


- 3D printer (or 3D printing service)
- Soldering iron and solder
- Small Phillips screwdriver
- microSD card reader (for your computer)
- A computer with [Raspberry Pi Imager](https://www.raspberrypi.com/software/) installed
- Tweezers or pliers
- Sticky putty (for holding the battery in place)
- Wire stripper and cutter
- Heatshrink tubing or electrical tape

## Step 1: Prepare the SD Card

1. Insert the microSD card into your computer.
2. Open Raspberry Pi Imager.
3. Select the settings:
   - **Device**: Raspberry Pi Zero 2 W
   - **OS**: Raspberry Pi OS (other) > Raspberry Pi OS Lite (64-bit)
   - **Hostname**: `reframe`
   - **Username**: `cam`
   - **Password**: your choice (but write it down somewhere safe)
   - **WiFi**: enter your home network name and password. If you want to use the camera on the go, also add your phone's hotspot (you can add multiple networks)
   - **Services**: Enable SSH with password authentication
4. Write the image and eject the card.

The username `cam` is required by the current service and updater configuration.

## Step 2: Soldering & Wiring Preparations

In this step, we will prepare the wire connections for the shutter button, the PiSugar 3 battery board, and the USB-C breakout board.

PiSugar 3 Solder Pad Diagram
*Simplified PiSugar 3 soldering points for this build. For the button connector, solder black to Pad 10 (Power Button Pad) and red to BAT+ / Pad 2. For the USB-C connector, solder black to Pad 1 (GND) and red to Pad 8 (5V Input Pad).*

### A. Soldering the Shutter Button
Prepare the 12mm stainless steel push button by soldering wires to its terminals.

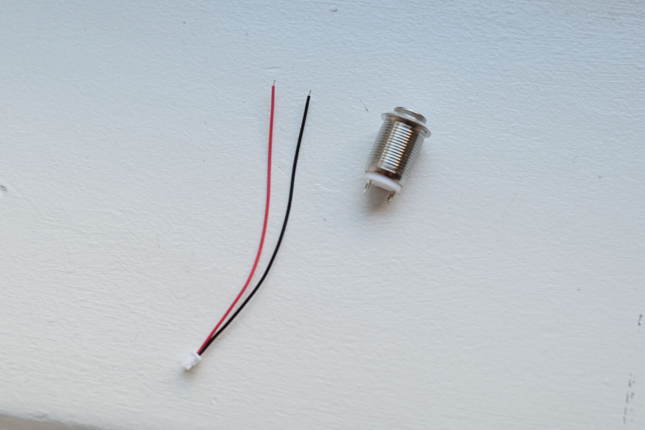
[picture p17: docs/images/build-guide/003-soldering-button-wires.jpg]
Soldering Button Wires

*Tin the leads and the terminals of the push button before soldering.*

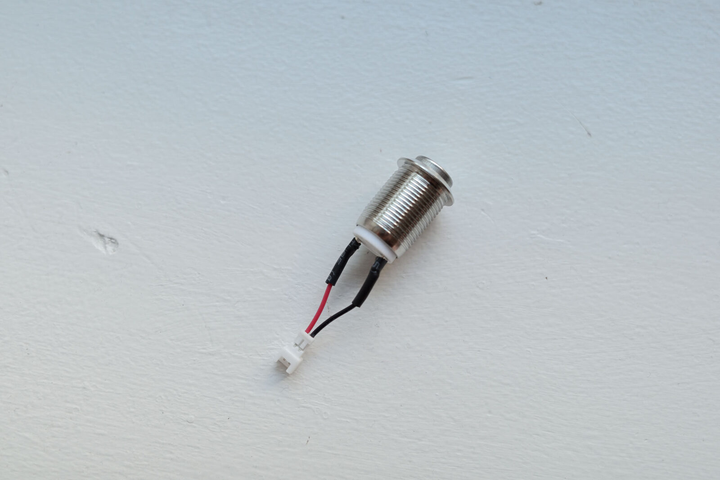
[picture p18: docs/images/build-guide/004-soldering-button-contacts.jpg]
Soldering Button Contacts

*Securely solder the wires to the contacts. Use heat shrink or electrical tape to prevent shorts.*

### B. Soldering the USB-C Breakout Board
Prepare the USB-C breakout board to expose the charging port through the enclosure.

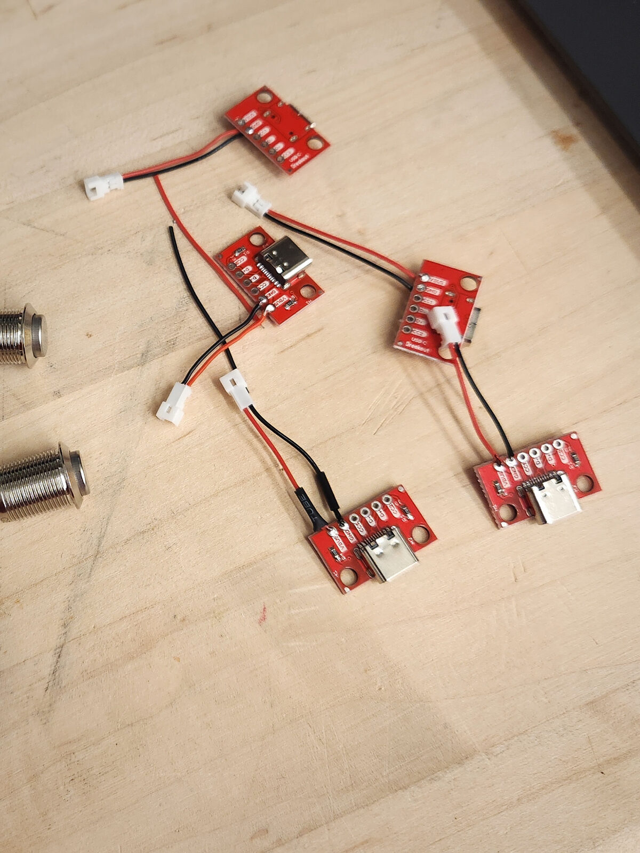
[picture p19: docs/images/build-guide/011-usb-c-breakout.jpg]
USB-C Breakout Prepared

*Solder the power wires to the VBUS and GND pads on the breakout board.*

### C. Soldering the PiSugar 3 Battery Board
Take two JST 1.25mm 2-Pin Micro Connectors. Connect the two wires of each connector to the pads on the PiSugar 3 board. You need to connect two connectors - one for the power button, and one for the USB-C charging board.

PiSugar 3 Solder Pad Diagram

For a detailed PiSugar PCB diagram, see the [PiSugar 3 wiki](https://github.com/PiSugar/PiSugar/wiki/PiSugar-3-Series).

| Position | Name | Description |
|:---:|---|---|
| **1** | GND | There are several ground pins you can use for this. |
| **2** | BAT | The battery should be soldered on there already, just add an extra solder on top. |
| **8** | 5V Input Pad | Connects to our external USB board |
| **10** | Power Button Pad | Used to trigger the power button when connected to Pad 2. |

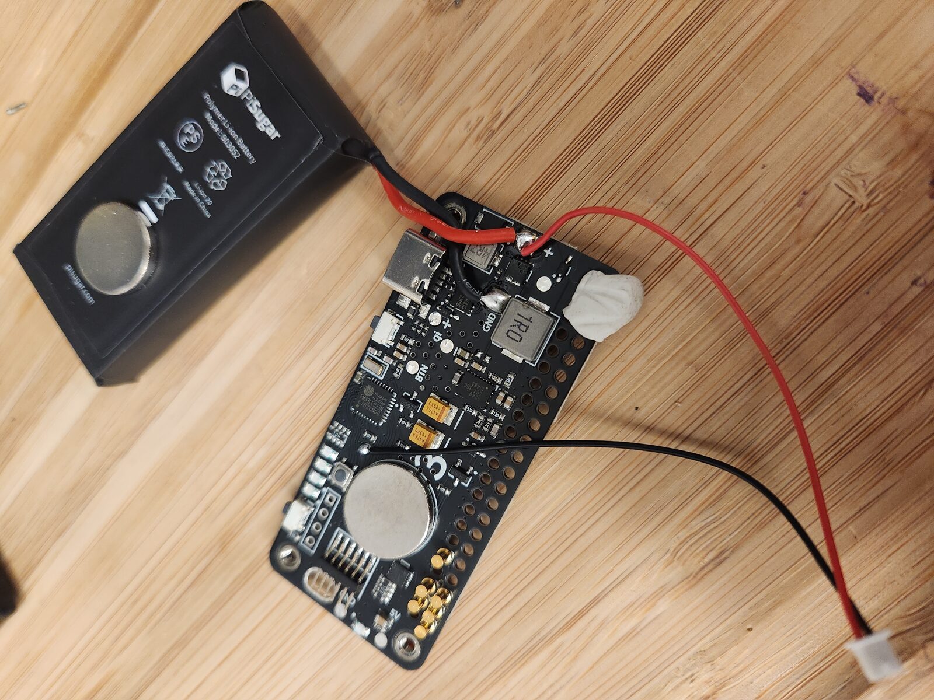
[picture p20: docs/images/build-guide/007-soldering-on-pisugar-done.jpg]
Soldering PiSugar Done

*Carefully solder the power button wires. Sticky putty helps hold the board in place. Watch out for the magnet.*

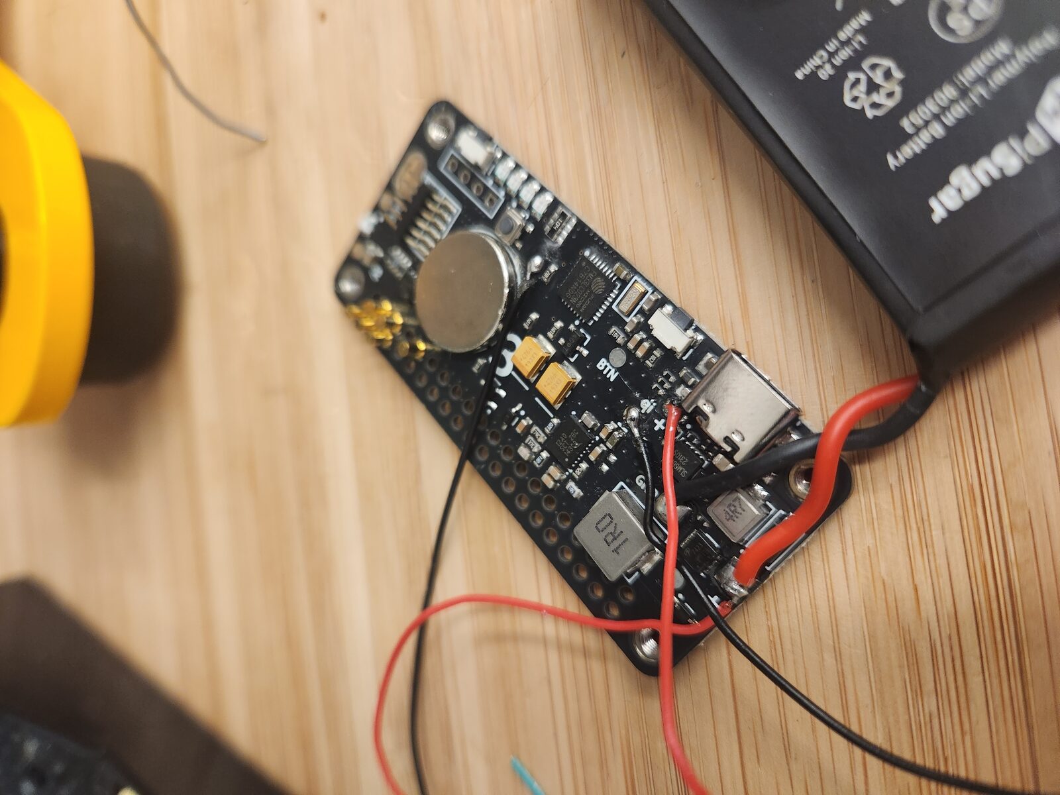
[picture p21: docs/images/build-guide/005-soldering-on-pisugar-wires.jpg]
Soldering PiSugar Wires

*Completed soldering on the PiSugar 3 battery board.*

### D. Bench Test the Power Wiring
Before putting everything into the enclosure, test the soldered button and charging connections while the PiSugar board is still easy to reach.

1. Plug the external button JST connector into the PiSugar button harness.
2. Press the button and confirm the PiSugar reacts. On a new PiSugar 3, accidental-touch prevention may still be enabled, so power-on may require a short press followed by a long press.
3. Plug a USB-A to USB-C cable into the external USB-C breakout board.
4. Confirm the PiSugar charging LEDs turn on.
5. Unplug USB-C and power the board off before continuing the mechanical assembly.

If either test fails, stop and recheck the pad wiring before mounting the stack in the case.

## Step 3: Component Mounting & Enclosure Prep

In this step, we prepare the ePaper display and mount the camera, button, and wrist strap into the 3D-printed enclosure.

### A. Preparing the Display
Unbox the Waveshare 4" ePaper display HAT+ and prepare it for mounting. Screw on the included standoffs – you only need the two next to the header.

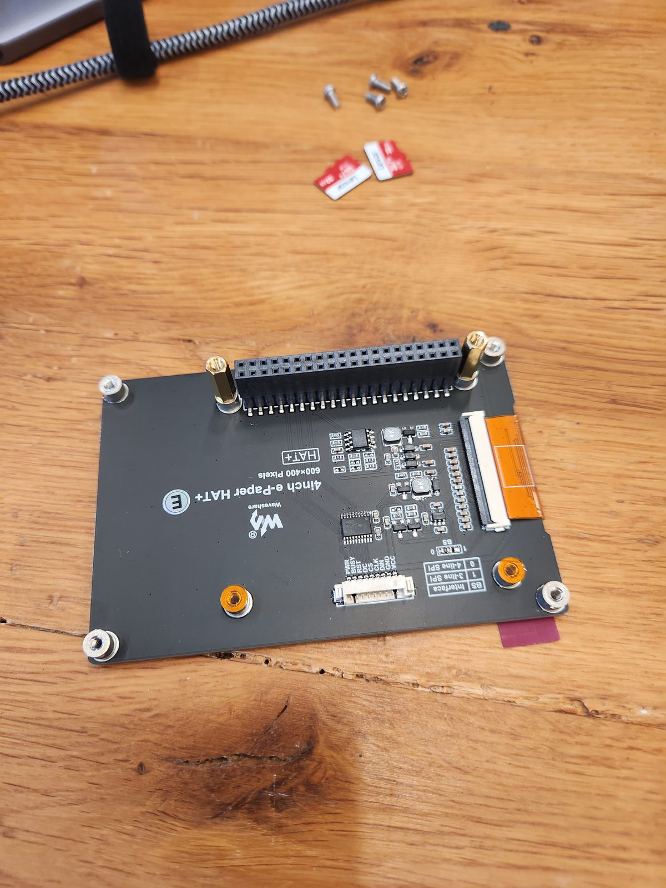
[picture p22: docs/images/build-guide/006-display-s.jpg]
ePaper Display Front

*The back of the Waveshare Spectra 6 ePaper display. The 40-pin header can't be removed.*

Insert the display into the holes of the 3D printed enclosure, and secure it with 4 20mm M2.5 standoffs.

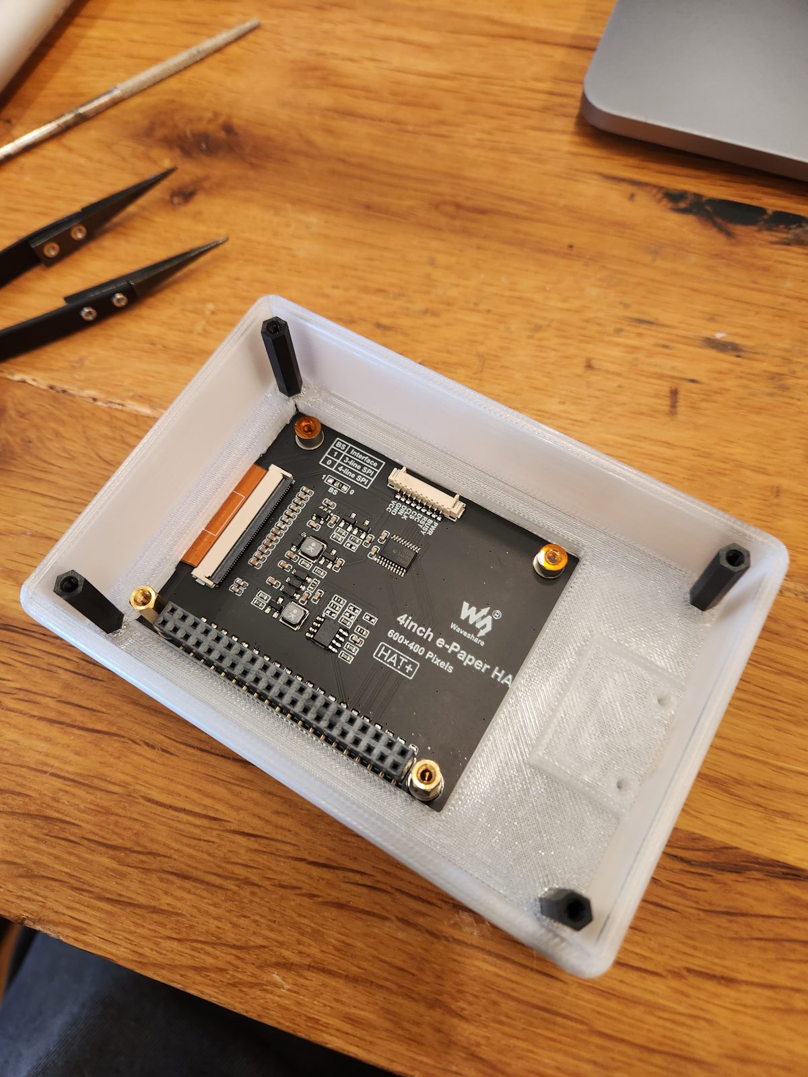
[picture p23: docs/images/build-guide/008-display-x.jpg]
ePaper Display Back View 1

*Rear side of the display showing the interface connectors.*

Once the display is secured, you can snap on the protective bezel.

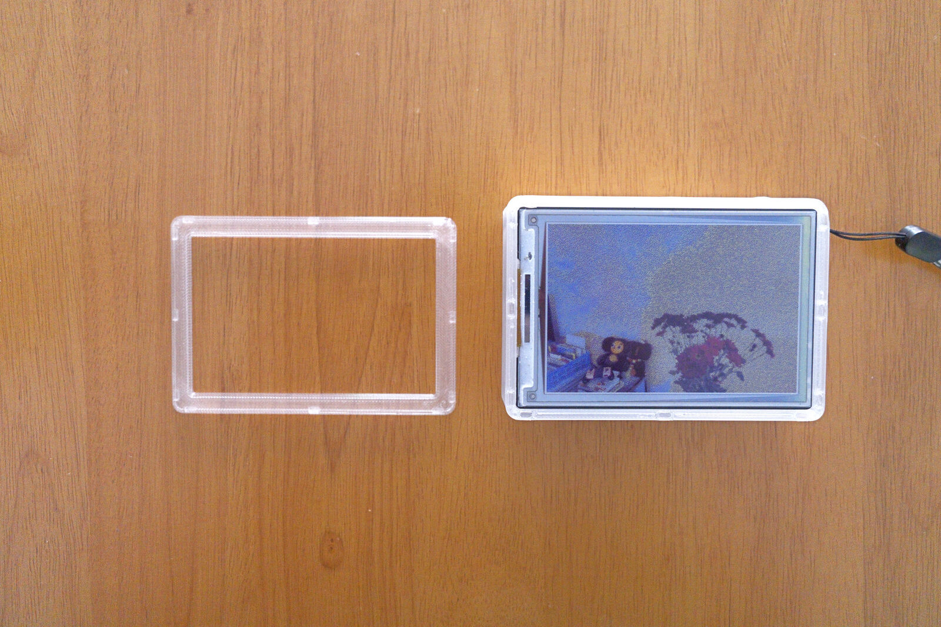
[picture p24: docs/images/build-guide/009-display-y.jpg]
ePaper Display Back View 2

*Ignore the wrist strap in this image, we're adding it later.*

Just align the holes and push, if the tolerance is right it should snap in.

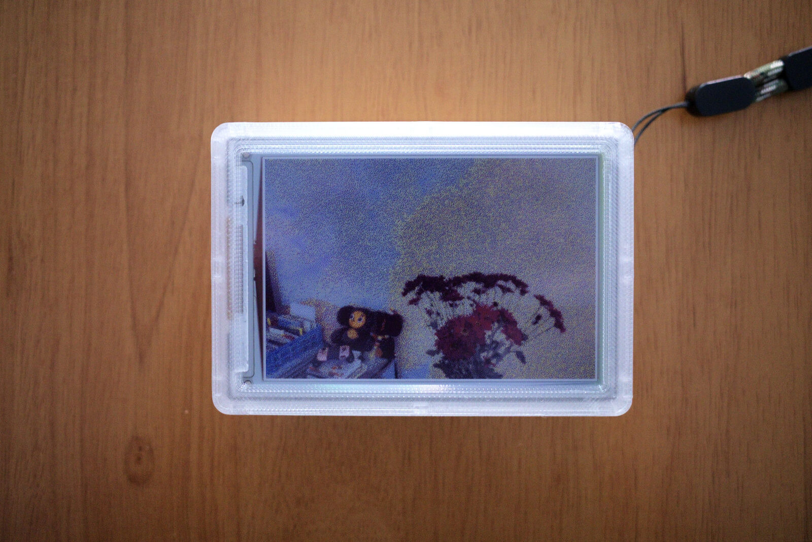
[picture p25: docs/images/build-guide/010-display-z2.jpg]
ePaper Display Back View 3


### B. Mounting the USB-C Board

Mount the USB-C breakout board to the case and screw it in using the M2.5 screws.

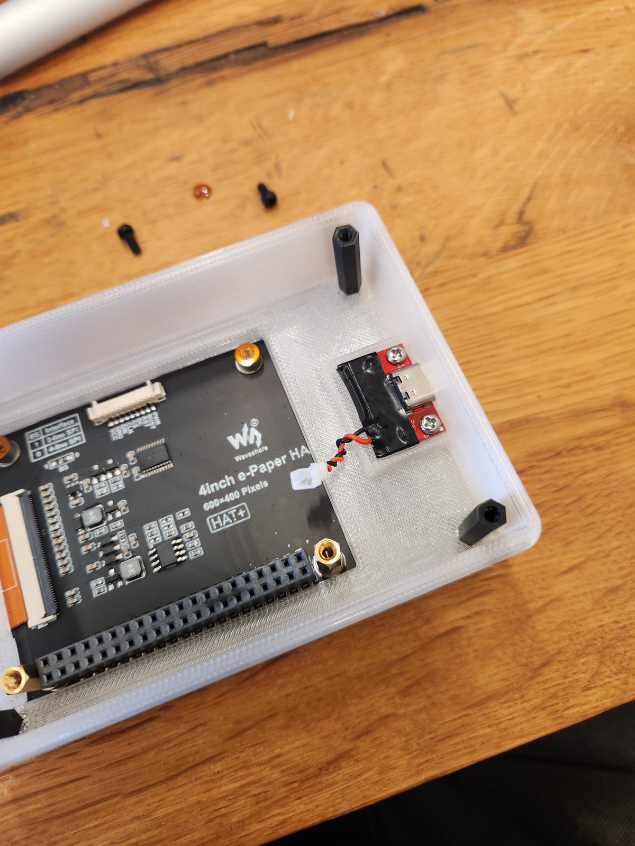
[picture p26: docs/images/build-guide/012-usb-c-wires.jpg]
USB-C Board Mounted


### C. Mounting the Shutter Button & Wrist Strap
Install the wrist strap by sliding it in through the outside hole, then positioning the ear so it holds the spacer.

Slide the button into the 3D-printed shell and secure it from the other side using the ring it came with.

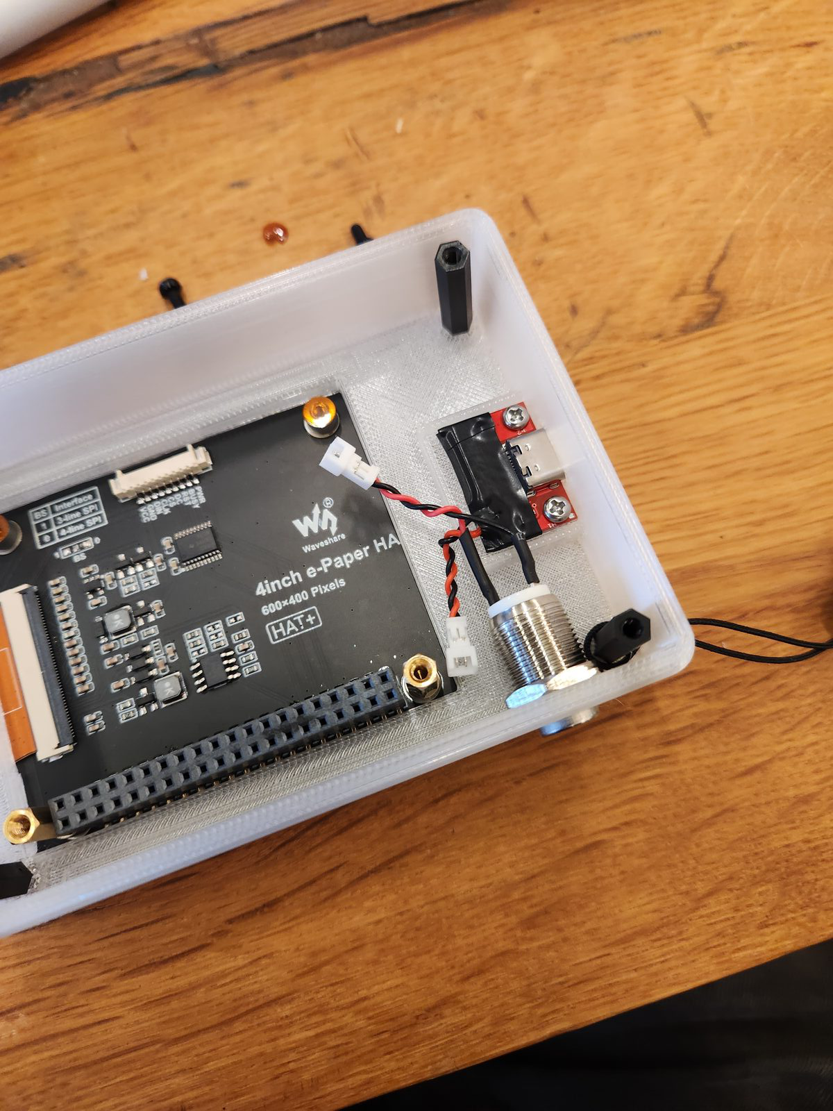
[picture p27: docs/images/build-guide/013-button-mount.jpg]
Button Mounted

*Screw the 12mm stainless steel push button into its designated slot in the enclosure.*

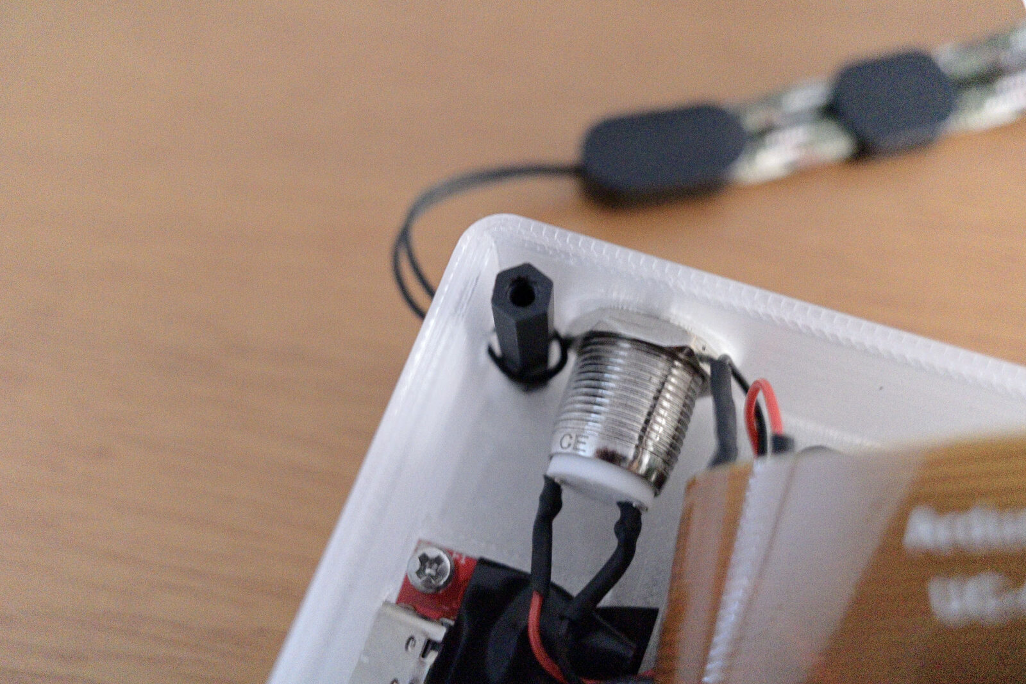
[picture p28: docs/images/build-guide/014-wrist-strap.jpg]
Wrist Strap Mounted

*Thread the wrist strap loop through the anchor holes in the case.*

### D. Mounting the Camera Module 3
Mount the Raspberry Pi Camera Module 3 to the front plate.

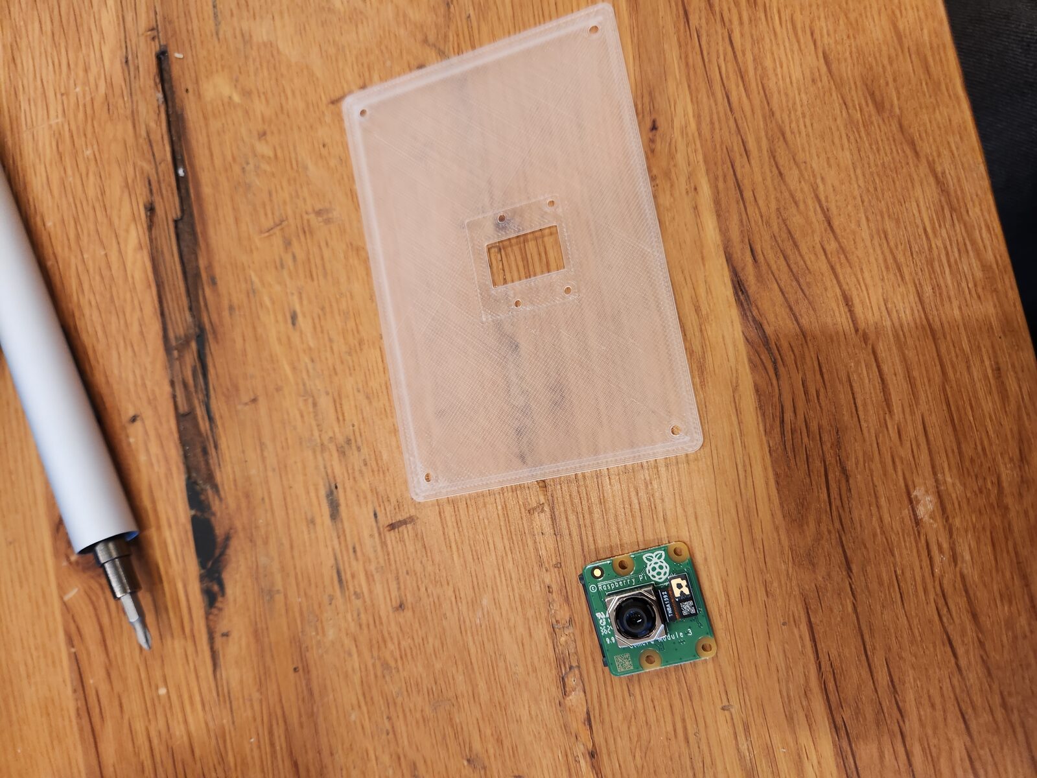
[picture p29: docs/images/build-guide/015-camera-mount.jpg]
Camera Alignment

*Align the camera module lens with the front plate cutout.*

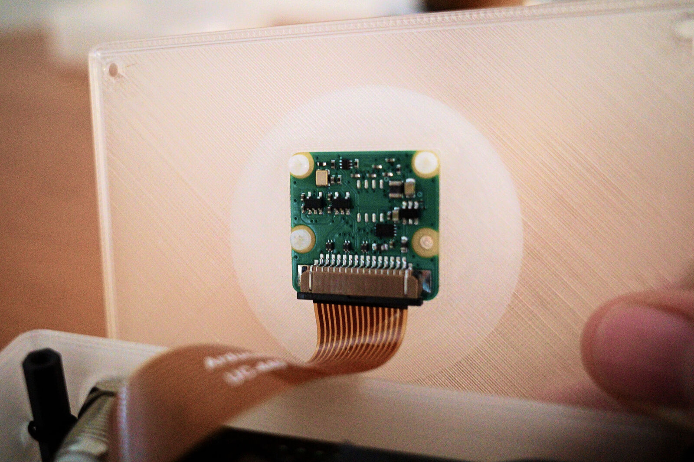
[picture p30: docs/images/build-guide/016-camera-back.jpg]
Camera Screws Back

*Secure the camera module using the M2 screws (one's missing from this photo). Ignore the ribbon cable for now, we'll snap it in later.*

The screws should friction fit into the protective front ring.

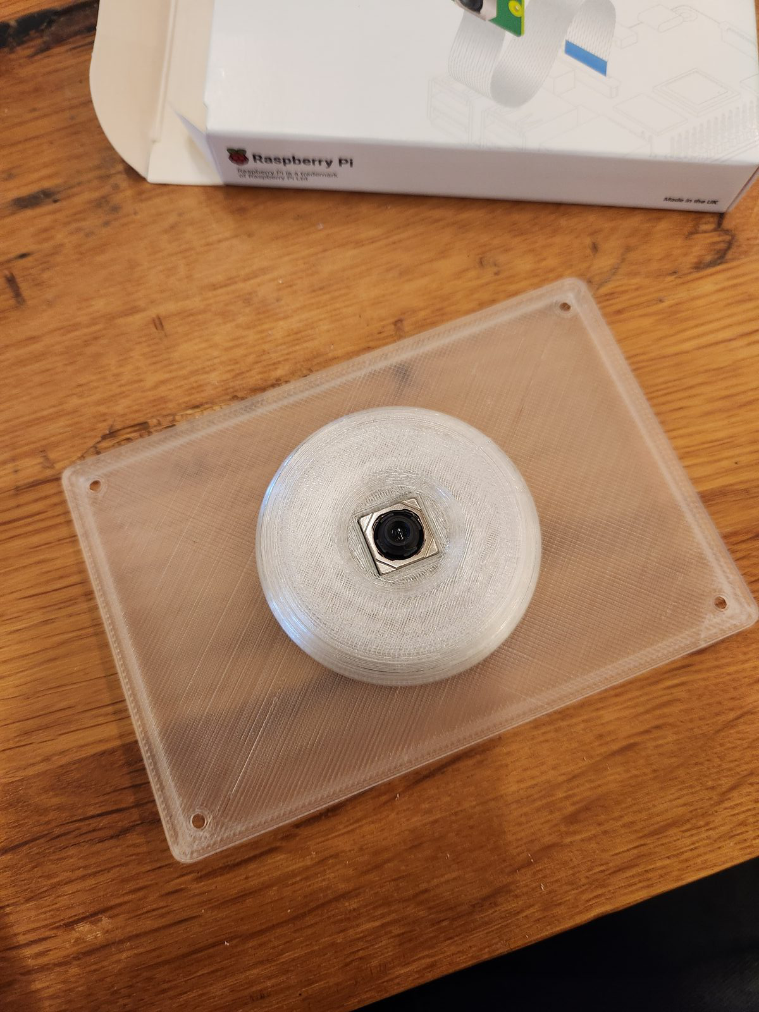
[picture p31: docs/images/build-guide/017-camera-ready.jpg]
Camera Mounted Front View

*The camera module securely mounted to the front faceplate.*

## Step 4: Assembling the Electronics Stack

Now, we assemble the main compute stack by pairing the Raspberry Pi Zero 2 W with the PiSugar 3 battery board and connecting the camera.

### A. Mating the Pi and PiSugar
Mount the Raspberry Pi Zero 2 W directly onto the PiSugar 3 battery board.

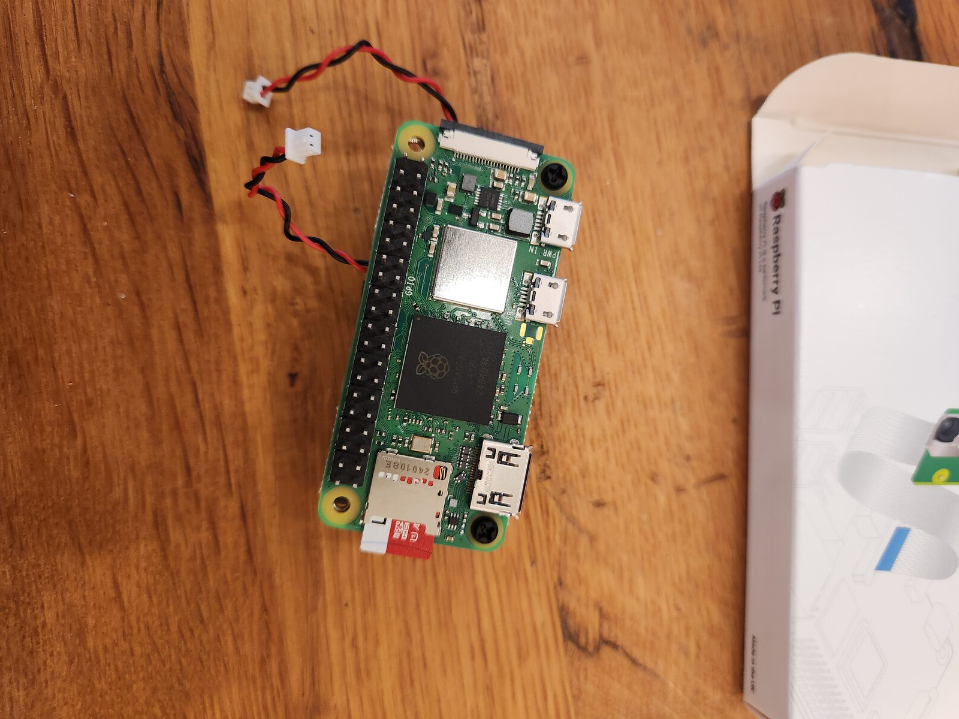
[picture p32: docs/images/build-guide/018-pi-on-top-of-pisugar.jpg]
Pi on PiSugar

*Place the Pi Zero 2 W on top of the PiSugar 3. The pogo pins will contact the power pads on the back of the Pi.*

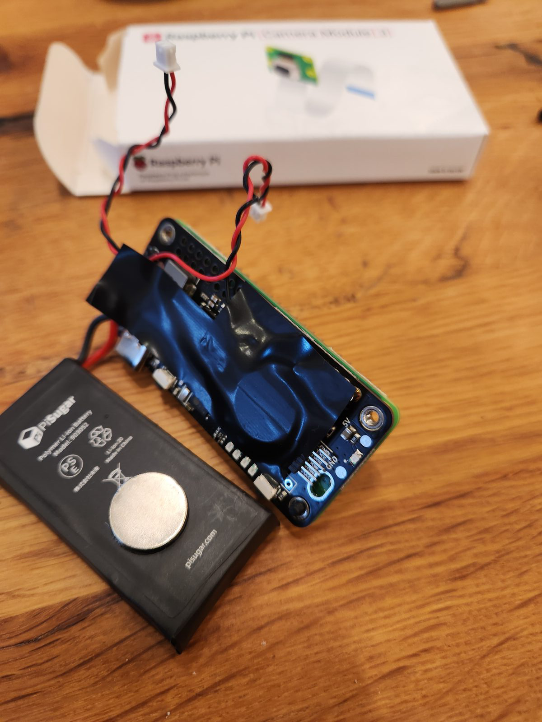
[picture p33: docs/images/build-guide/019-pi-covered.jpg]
Pi Stack Secured

*Secure the Pi to the PiSugar using the M2.5 screws. Covering the back of the PiSugar with electrical tape helps prevent shorts.*

### B. Connecting the Camera Ribbon Cable
Connect the camera ribbon cable to the Pi Zero.

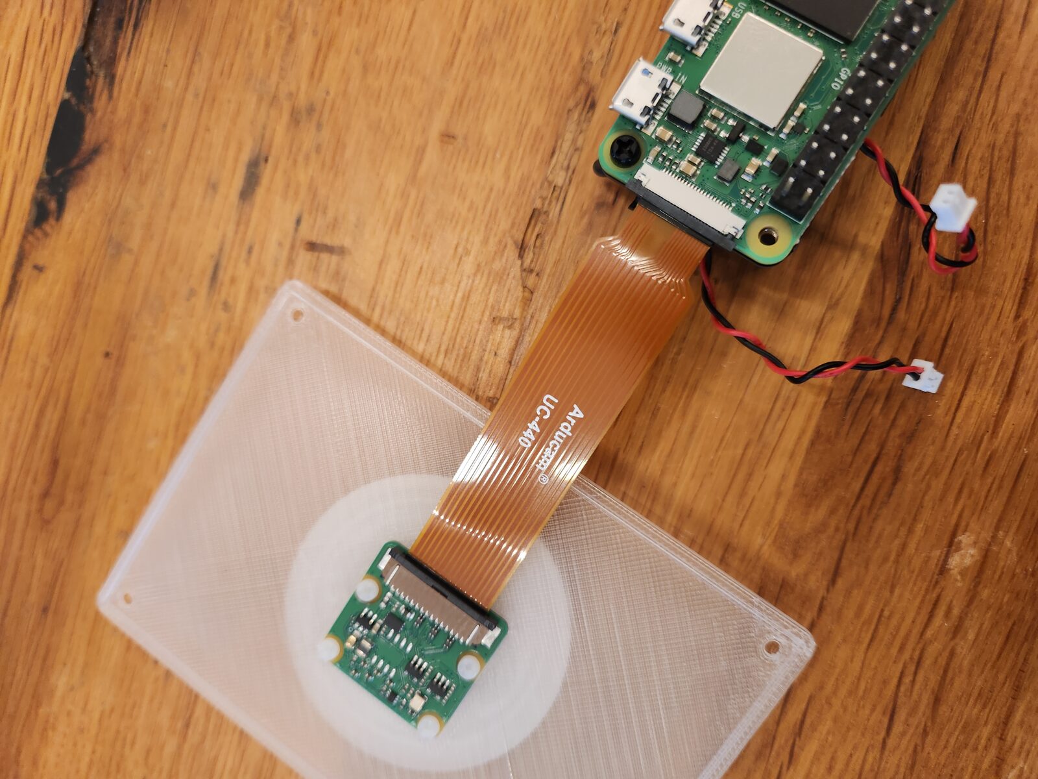
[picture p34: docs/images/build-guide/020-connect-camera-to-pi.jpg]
Connect Camera Cable

*Lift the latch on the Pi Zero camera port, slide the ribbon cable in, and clamp it down securely.*

### C. Insert the SD Card
Insert your flashed SD Card into the Pi Zero 2 W.

## Step 5: Final Enclosure Assembly

Fit all the sub-assemblies together inside the enclosure and wire up the remaining connections.

### A. Fitting the stack in the Case
Position the main electronics stack inside the 3D-printed enclosure. The Pi 40-pin header should fit into the header on the display.

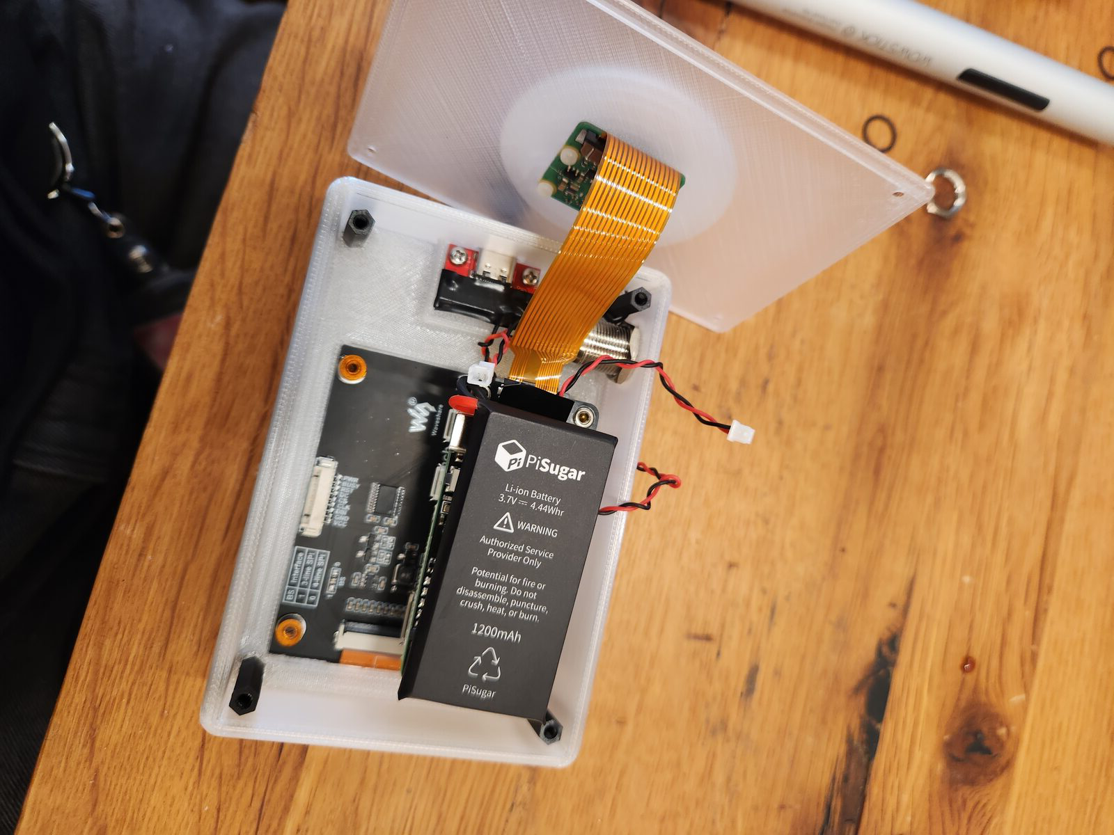
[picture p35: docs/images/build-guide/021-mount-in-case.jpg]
Mount Stack in Case

*Carefully position the Pi/battery stack into the bottom shell.*

### B. Connecting Wires
Attach the shutter button and USB-C breakout board connectors to the main board.

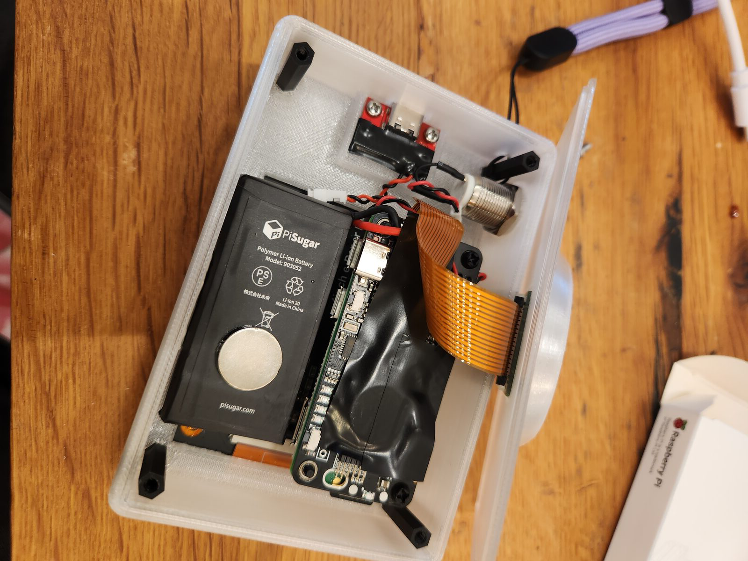
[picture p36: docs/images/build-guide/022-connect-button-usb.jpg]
Connect Button and USB Wires

*Plug the JST 1.25mm connectors from the button and USB-C breakout board into the Pi/PiSugar headers.*

Remove the battery from the magnet and lay it flat next to the board. You can use some sticky putty to keep it in place so it doesn't wiggle.

### C. Screwing the Case Together
Secure the front cover plates using the four M2.5 screws.

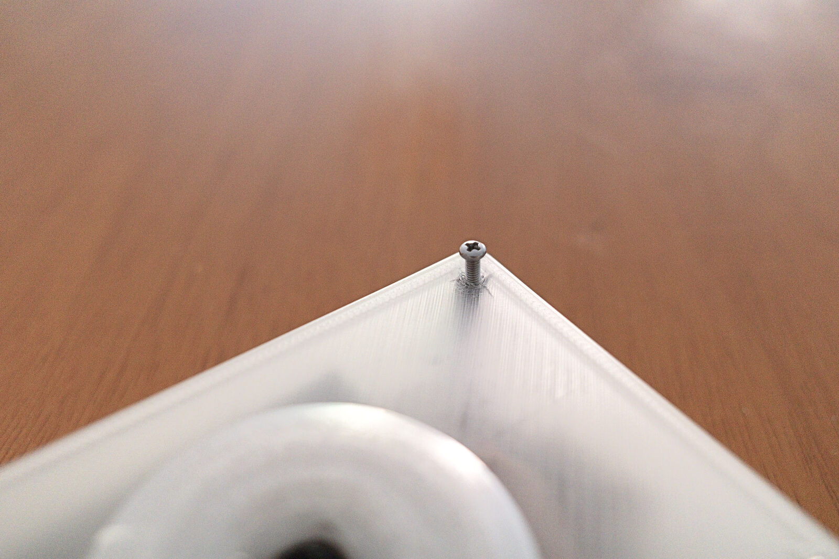
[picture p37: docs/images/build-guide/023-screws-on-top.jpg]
Screws on Top

*Insert the M2.5 screws into the corner holes to fasten the enclosure assembly.*

## Step 6: Software Setup & First Boot

With assembly complete, configure the software and boot up your reFrame camera. The first boot may still use the PiSugar 3's default accidental-touch prevention behavior, so use the short-press-then-long-press sequence if a single press does not power it on yet.

1. Power on the camera. On a new PiSugar 3, this may require a short press followed by a long press until the software setup disables accidental-touch prevention.
2. Follow the [Software Setup](software-setup.md) guide. During setup, reFrame uses PiSugar Power Manager to disable accidental-touch prevention so the camera powers on with a single press.
3. After setup, press once to power on. reFrame automatically takes and displays a photo when it boots.
4. While the camera is on, short-press the button to take another photo.
5. Long-press the button to shut the camera down.
6. If you leave the camera on, it automatically shuts down after 10 minutes of inactivity to prevent battery drain.

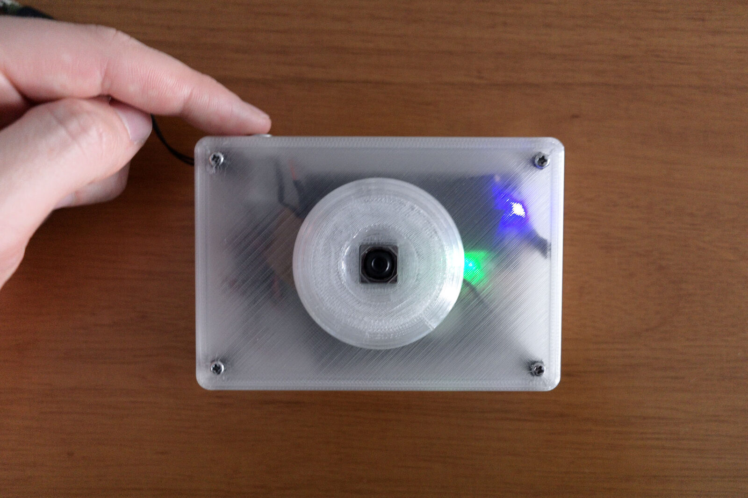
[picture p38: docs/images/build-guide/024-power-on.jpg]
First Boot

*Powering on the camera. The ePaper screen will cycle colors and refresh to display its very first capture.*

*Need help? Reach out via email or on [Instagram](https://instagram.com/reframe.camera).*

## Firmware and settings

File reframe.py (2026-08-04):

#!/usr/bin/env python3

import os
import sys
import json
import subprocess
import logging
import socket
from time import sleep

# Lazy-loaded by _lazy_import_pil() on first use
Image = None
ImageEnhance = None

def _lazy_import_pil():
    """Import PIL only when needed for image processing."""
    global Image, ImageEnhance
    if Image is None:
        from PIL import Image, ImageEnhance
    return Image, ImageEnhance

from picamera2 import Picamera2

from typing import Optional, Dict, Any

np = None

def _lazy_import_numpy():
    """Import NumPy only when image processing/display conversion needs it."""
    global np
    if np is None:
        import numpy as _np
        np = _np
    return np

# Lazy-loaded by _lazy_import_fastapi() on first use
_API_AVAILABLE = None
FastAPI = None
HTTPException = None
Request = None
uvicorn = None

def _lazy_import_fastapi():
    """Import FastAPI/uvicorn only when needed."""
    global _API_AVAILABLE, FastAPI, HTTPException, Request, uvicorn
    if _API_AVAILABLE is None:
        try:
            from fastapi import FastAPI, HTTPException, Request
            import uvicorn
            _API_AVAILABLE = True
        except Exception:
            _API_AVAILABLE = False
            FastAPI = None
            HTTPException = None
            Request = None
            uvicorn = None
    return _API_AVAILABLE

import threading
import time

# ═══════════════════════════════════════════════════════════════════
# HARDWARE: Display — defaults to Waveshare 4" ePaper Spectra 6
# The driver lives in waveshare_epd/. To use a different e-ink display,
# update the DISPLAY_* constants, ImageProcessor palette/buffer mapping, and
# the EInkDisplay adapter class below.
# ═══════════════════════════════════════════════════════════════════
libdir = os.path.join(os.path.dirname(os.path.dirname(os.path.realpath(__file__))), 'lib')
if os.path.exists(libdir):
    sys.path.append(libdir)

# Logging setup
logging.basicConfig(level=logging.INFO)

# Constants for file paths
BASE_PATH = os.path.dirname(os.path.realpath(__file__))
SAVE_PATH = os.path.join(BASE_PATH, "photos")
PROCESSED_PATH = os.path.join(BASE_PATH, "dithered_photos")
RUNTIME_PATH = os.path.join(BASE_PATH, ".runtime")
HDR_HELPER_PATH = os.path.join(BASE_PATH, "scripts", "enable_hdr.sh")
ORIGINAL_CAPTURE_EXTENSION = "jpg"
DEFAULT_CAPTURE_WIDTH = 3280
DEFAULT_CAPTURE_HEIGHT = 2464
DISPLAY_IMAGE_WIDTH = 600
DISPLAY_IMAGE_HEIGHT = 400
DISPLAY_PANEL_WIDTH = 400
DISPLAY_PANEL_HEIGHT = 600
DISPLAY_IMAGE_SIZE = (DISPLAY_IMAGE_WIDTH, DISPLAY_IMAGE_HEIGHT)
DISPLAY_PANEL_SIZE = (DISPLAY_PANEL_WIDTH, DISPLAY_PANEL_HEIGHT)
BUTTON_POLL_INTERVAL_SECONDS = 0.025

# Color palettes for dithering. We blend between the two to create a saturated look while preserving details.
# Idea from https://github.com/pimoroni/inky
DESATURATED_PALETTE = [
    [0, 0, 0],          # Black
    [255, 255, 255],    # White
    [0, 255, 0],        # Green
    [0, 0, 255],        # Blue
    [255, 0, 0],        # Red
    [255, 255, 0],      # Yellow
]

SATURATED_PALETTE = [
    [57, 48, 57],       # Muted Black
    [255, 255, 255],    # White
    [40, 91, 58],       # Muted Green
    [0, 128, 255],      # Muted Blue
    [156, 72, 75],      # Muted Red
    [208, 190, 71],     # Muted Yellow
]

def get_dashboard_access_info(hostname=None, ip_address=None):
    """Build the friendly dashboard URLs for this device."""
    if hostname is None:
        hostname = socket.gethostname()
    hostname = (hostname or "reframe").split(".")[0]

    if ip_address is None:
        ip_address = get_lan_ip_address()

    primary_url = f"http://{hostname}.local"
    fallback_url = f"http://{ip_address}" if ip_address else None
    marker = f"{primary_url}|{fallback_url or ''}"
    return {
        "hostname": hostname,
        "ip_address": ip_address,
        "primary_url": primary_url,
        "fallback_url": fallback_url,
        "marker": marker
    }


def get_lan_ip_address():
    """Return wlan0's usable IPv4 address, if it has one."""
    try:
        result = subprocess.run(
            ["ip", "-4", "-o", "addr", "show", "dev", "wlan0", "scope", "global"],
            capture_output=True,
            text=True,
            timeout=2
        )
        if result.returncode == 0:
            fields = result.stdout.split()
            for index, field in enumerate(fields[:-1]):
                if field != "inet":
                    continue
                ip_address = fields[index + 1].split("/", 1)[0]
                if _is_usable_lan_ip(ip_address):
                    return ip_address
    except Exception:
        pass

    return None


def _is_usable_lan_ip(ip_address):
    return (
        ip_address
        and "." in ip_address
        and not ip_address.startswith("127.")
        and not ip_address.startswith("169.254.")
    )


def _enable_camera_hdr():
    """Enable Camera Module 3 HDR after imports but before Picamera2 opens it."""
    if not os.path.isfile(HDR_HELPER_PATH):
        logging.warning("HDR helper not found at %s; continuing without HDR", HDR_HELPER_PATH)
        return

    try:
        result = subprocess.run([HDR_HELPER_PATH], timeout=4, check=False)
        if result.returncode != 0:
            logging.warning("HDR helper exited with status %s", result.returncode)
    except subprocess.TimeoutExpired:
        logging.warning("HDR helper timed out; continuing without HDR")
    except Exception as e:
        logging.warning("Could not run HDR helper: %s", e)


def _notify_systemd_ready(status):
    """Tell systemd startup capture dispatch is complete."""
    notify_socket = os.environ.get("NOTIFY_SOCKET")
    if not notify_socket:
        return

    address = notify_socket
    if address.startswith("@"):
        address = "\0" + address[1:]

    try:
        with socket.socket(socket.AF_UNIX, socket.SOCK_DGRAM) as notifier:
            notifier.connect(address)
            notifier.send(f"READY=1\nSTATUS={status}".encode("utf-8"))
        logging.info("Notified systemd: %s", status)
    except Exception as e:
        logging.error("Could not notify systemd that startup is ready: %s", e)


def _auto_display_enabled(settings_path):
    """Read only the startup display flag before CameraManager is constructed."""
    try:
        with open(settings_path, "r") as settings_file:
            settings = json.load(settings_file)
        display_settings = settings.get("display", {})
        if isinstance(display_settings, dict):
            return display_settings.get("auto_display", True)
    except (OSError, json.JSONDecodeError, AttributeError):
        pass
    return True


def render_dashboard_qr_image(access_info):
    """Render a dashboard QR screen for the ePaper display."""
    Image, _ = _lazy_import_pil()
    from PIL import ImageDraw
    import qrcode

    primary_url = access_info["primary_url"]
    fallback_url = access_info.get("fallback_url")

    qr_url = fallback_url or primary_url
    qr = qrcode.QRCode(border=2, box_size=8)
    qr.add_data(qr_url)
    qr.make(fit=True)
    qr_image = qr.make_image(fill_color="black", back_color="white").convert("RGB")
    qr_image = qr_image.resize((250, 250))

    canvas = Image.new("RGB", DISPLAY_IMAGE_SIZE, "white")
    canvas.paste(qr_image, (30, 75))

    draw = ImageDraw.Draw(canvas)
    x = 315
    draw.text((x, 90), "reFrame dashboard", fill="black")
    draw.text((x, 125), primary_url, fill="black")
    if fallback_url:
        draw.text((x, 170), "If that does not open:", fill="black")
        draw.text((x, 200), fallback_url, fill="black")
    draw.text((x, 255), "Scan with your phone", fill="black")
    draw.text((x, 285), "to open photos.", fill="black")

    return canvas

class CameraManager:
    """Picamera2 camera adapter.

    To support a different camera stack, keep this public surface compatible:
    load/reload settings, configure/start the camera, capture a PIL RGB image,
    optionally save a file capture, and expose timeout/shutdown helpers used by
    CameraSystem. The rest of the app only expects capture_image_with_metadata()
    to return (result_dict, PIL_image).
    """

    def __init__(self, settings_path="settings.json"):
        self.settings_path = settings_path
        self.settings = self.load_settings()
        self.picam2 = Picamera2()
        self.last_activity_monotonic = time.monotonic()
        self._has_captured = False  # Track if we've taken at least one photo (for adaptive AF)
        self.configure_camera()

    def load_settings(self):
        """Load camera settings from JSON file."""
        try:
            with open(self.settings_path, 'r') as f:
                return json.load(f)
        except (FileNotFoundError, json.JSONDecodeError) as e:
            logging.warning(f"Could not load settings from {self.settings_path}: {e}")
            # Return default settings
            return {
                "camera": {
                    "resolution": {"width": DEFAULT_CAPTURE_WIDTH, "height": DEFAULT_CAPTURE_HEIGHT},
                    "exposure_value": 0,
                    "sharpness": 3,
                    "autofocus_mode": 2
                },
                "processing": {
                    "saturation": 0.6,
                    "brightness_factor": 1.1,
                    "color_factor": 1.4,
                    "dithering_method": "floyd_steinberg",
                    "bayer_size": 4,
                    "threshold_scale": 1.0
                },
                "display": {
                    "auto_display": True,
                    "display_timeout": 0
                },
                "system": {
                    "auto_refresh_interval": 30,
                    "auto_timeout_minutes": 10,
                    "auto_timeout_enabled": True,
                    "show_dashboard_qr_on_wifi_connect": True
                }
            }

    def reload_settings(self):
        """Reload settings from file and reconfigure camera."""
        old_settings = self.settings.copy()
        self.settings = self.load_settings()

        # Only reconfigure if camera settings changed
        camera_changed = old_settings.get("camera", {}) != self.settings.get("camera", {})
        if camera_changed:
            logging.info("Camera settings changed, reconfiguring...")
            self.configure_camera()

        return self.settings

    def apply_camera_settings(self, camera_settings=None):
        """Apply specific camera settings without full reconfiguration."""
        if camera_settings is None:
            camera_settings = self.settings.get("camera", {})

        # Update only the controls that can be changed while running
        controls = {}

        if "exposure_value" in camera_settings:
            controls["ExposureValue"] = camera_settings["exposure_value"]
        if "sharpness" in camera_settings:
            controls["Sharpness"] = camera_settings["sharpness"]
        if "autofocus_mode" in camera_settings:
            controls["AfMode"] = camera_settings["autofocus_mode"]

        # Apply controls one by one to handle unsupported controls gracefully
        for control_name, control_value in controls.items():
            try:
                self.picam2.set_controls({control_name: control_value})
                logging.info(f"Applied {control_name}: {control_value}")
            except Exception as e:
                logging.warning(f"Could not set {control_name}: {e}")

    def capture_photo_with_metadata(self, file_path=None, fast_mode=False):
        """Capture a photo and return metadata like the dashboard API."""
        if file_path is None:
            # Use FileManager to get consistent naming
            file_manager = FileManager(SAVE_PATH, PROCESSED_PATH)
            file_path = file_manager.get_new_file_path(SAVE_PATH, ORIGINAL_CAPTURE_EXTENSION)

        try:
            self.capture_photo(file_path, fast_mode=fast_mode)

            # Get file info
            file_size = os.path.getsize(file_path)

            return {
                "success": True,
                "photo_id": os.path.splitext(os.path.basename(file_path))[0],
                "original_path": file_path,
                "processed_path": None,  # Will be set after processing
                "file_size": file_size,
                "message": "Photo captured successfully"
            }
        except Exception as e:
            logging.error(f"Error capturing photo: {e}")
            return {
                "success": False,
                "error": str(e),
                "message": f"Photo capture failed: {str(e)}"
            }

    def capture_image_with_metadata(self, file_path=None, fast_mode=False):
        """Capture a PIL image in memory and return metadata for async saving."""
        if file_path is None:
            file_manager = FileManager(SAVE_PATH, PROCESSED_PATH)
            file_path = file_manager.get_new_file_path(SAVE_PATH, ORIGINAL_CAPTURE_EXTENSION)

        try:
            image = self.capture_image(fast_mode=fast_mode)
            return {
                "success": True,
                "photo_id": os.path.splitext(os.path.basename(file_path))[0],
                "original_path": file_path,
                "processed_path": None,
                "file_size": None,
                "message": "Photo captured successfully"
            }, image
        except Exception as e:
            logging.error(f"Error capturing photo: {e}")
            return {
                "success": False,
                "error": str(e),
                "message": f"Photo capture failed: {str(e)}"
            }, None


    def configure_camera(self):
        """Configure the camera settings."""
        camera_settings = self.settings.get("camera", {})
        resolution = camera_settings.get(
            "resolution",
            {"width": DEFAULT_CAPTURE_WIDTH, "height": DEFAULT_CAPTURE_HEIGHT}
        )

        # Safely stop the camera before reconfiguring to avoid runtime errors
        try:
            self.picam2.stop()
        except Exception:
            pass

        camera_config = self.picam2.create_still_configuration(
            main={"size": (resolution["width"], resolution["height"])}
        )

        # Build controls dictionary from settings
        controls = {
            "ExposureValue": camera_settings.get("exposure_value", 0),
            "Sharpness": camera_settings.get("sharpness", 3)
        }


        camera_config["controls"] = controls

        try:
            self.picam2.configure(camera_config)
        except Exception as e:
            logging.error(f"Error configuring camera: {e}")
            # Try with basic configuration without custom controls
            basic_config = self.picam2.create_still_configuration(
                main={"size": (resolution["width"], resolution["height"])}
            )
            self.picam2.configure(basic_config)
            logging.info("Using basic camera configuration")

        # Set autofocus mode safely
        try:
            af_mode = camera_settings.get("autofocus_mode", 2)
            self.picam2.set_controls({"AfMode": af_mode})
        except Exception as e:
            logging.warning(f"Could not set autofocus mode: {e}")

        self.picam2.start()

    def update_activity_time(self):
        """Update the last activity timestamp."""
        self.last_activity_monotonic = time.monotonic()

    def get_inactivity_seconds(self):
        """Return elapsed inactivity without being affected by clock corrections."""
        return max(0, time.monotonic() - self.last_activity_monotonic)

    def is_timeout_enabled(self):
        """Check if auto-timeout is enabled in settings."""
        return self.settings.get("system", {}).get("auto_timeout_enabled", True)

    def get_timeout_minutes(self):
        """Get the timeout duration in minutes from settings."""
        return self.settings.get("system", {}).get("auto_timeout_minutes", 10)

    def get_shutdown_warning_seconds(self):
        """Get how long before auto-shutdown to warn the user."""
        return self.settings.get("system", {}).get("shutdown_warning_seconds", 60)

    def is_shutdown_buzzer_enabled(self):
        """Check if the shutdown warning buzzer is enabled."""
        return self.settings.get("system", {}).get("shutdown_buzzer_enabled", True)

    def get_shutdown_buzzer_pin(self):
        """Get the BCM GPIO pin used for the shutdown warning buzzer."""
        return self.settings.get("system", {}).get("shutdown_buzzer_pin", 23)

    def is_timeout_exceeded(self):
        """Check if the timeout period has been exceeded."""
        if not self.is_timeout_enabled():
            return False

        timeout_seconds = self.get_timeout_minutes() * 60
        elapsed = self.get_inactivity_seconds()
        return elapsed > timeout_seconds

    def shutdown_system(self):
        """Safely shutdown the entire Raspberry Pi system to save battery."""
        try:
            timeout_minutes = self.get_timeout_minutes()
            logging.info(f"System has been inactive for {timeout_minutes} minutes. Shutting down to save battery...")
            logging.info("To use the camera again, manually power on the Raspberry Pi")
            # Give a moment for logging to flush
            time.sleep(2)
            # Execute system shutdown command
            subprocess.run(["sudo", "shutdown", "-h", "now"], check=True)
            return True
        except Exception as e:
            logging.error(f"Error shutting down system: {e}")
            return False

    def capture_photo(self, file_path, fast_mode=False):
        """Capture a photo and save it to the specified file path."""
        self._settle_autofocus(fast_mode)
        self.picam2.capture_file(file_path)  # Capture the photo
        logging.info(f"Photo saved to {file_path}")

    def capture_image(self, fast_mode=False):
        """Capture a photo into memory as a PIL image."""
        self._settle_autofocus(fast_mode)
        image = self.picam2.capture_image("main")
        logging.info("Photo captured to memory")
        return image

    def _settle_autofocus(self, fast_mode=False):
        """Give autofocus a short settle window before capture."""
        self.update_activity_time()
        autofocus_mode = self.settings.get("camera", {}).get("autofocus_mode", 2)
        if fast_mode:
            sleep(0.1)  # Shorter autofocus for startup
            logging.info("Fast autofocus mode: 0.1s delay")
        elif self._has_captured and autofocus_mode == 2:
            logging.info("Continuous autofocus already active: no settle delay")
        elif self._has_captured:
            sleep(0.1)  # Sensor already focused from previous capture
            logging.info("Adaptive autofocus: 0.1s delay (sensor pre-focused)")
        else:
            sleep(0.3)  # First capture needs full autofocus settle time
        self._has_captured = True
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

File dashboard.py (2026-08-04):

#!/usr/bin/env python3

import os
import json
import sys
import logging
import asyncio
import time
import shutil
import math
import tempfile
import threading
from io import BytesIO
from datetime import datetime, timezone
from pathlib import Path
from typing import List, Dict, Any, Optional
from fastapi import FastAPI, HTTPException, Request, BackgroundTasks
from fastapi.responses import FileResponse, HTMLResponse, Response
from starlette.background import BackgroundTask
import httpx
from PIL import Image

CAMERA_AVAILABLE = False

# Constants
BASE_PATH = os.path.dirname(os.path.realpath(__file__))
PHOTOS_PATH = os.path.join(BASE_PATH, "photos")
DITHERED_PHOTOS_PATH = os.path.join(BASE_PATH, "dithered_photos")
SETTINGS_PATH = os.path.join(BASE_PATH, "settings.json")
USER_DATA_PATHS = ["settings.json", "photos", "dithered_photos"]
UPDATE_HELPER_PATH = "/usr/local/sbin/reframe-apply-update"
UPDATE_PENDING_PATH = os.path.join(BASE_PATH, ".runtime", "update_pending")

os.makedirs(PHOTOS_PATH, exist_ok=True)
os.makedirs(DITHERED_PHOTOS_PATH, exist_ok=True)

app = FastAPI(title="Reframe Dashboard", description="Control & Gallery Interface for Reframe Camera")


def prepare_dithered_export(image_path: str, upscale_2x: bool) -> tuple[bytes, str, str]:
    """Read a dithered image, optionally returning a lossless 2x PNG export."""
    source_path = Path(image_path)
    if not upscale_2x:
        return source_path.read_bytes(), source_path.name, "image/png"

    with Image.open(source_path) as image:
        resampling = getattr(Image, "Resampling", Image)
        enlarged = image.resize(
            (image.width * 2, image.height * 2),
            resampling.NEAREST
        )
        output = BytesIO()
        enlarged.save(output, format="PNG")

    return output.getvalue(), f"{source_path.stem}.png", "image/png"


class SettingsValidationError(ValueError):
    pass


def validate_settings(settings: Dict[str, Any]) -> None:
    """Validate persisted settings against the hardware and dashboard contract."""
    if not isinstance(settings, dict):
        raise SettingsValidationError("Settings must be a JSON object")

    def section(parent: Dict[str, Any], key: str, path: str) -> Dict[str, Any]:
        value = parent.get(key, {})
        if not isinstance(value, dict):
            raise SettingsValidationError(f"{path} must be an object")
        return value

    def number(value: Any, path: str, minimum: float, maximum: float) -> None:
        if isinstance(value, bool) or not isinstance(value, (int, float)) or not math.isfinite(value):
            raise SettingsValidationError(f"{path} must be a number")
        if value < minimum or value > maximum:
            raise SettingsValidationError(f"{path} must be between {minimum} and {maximum}")

    def integer(value: Any, path: str, minimum: int, maximum: int) -> None:
        if isinstance(value, bool) or not isinstance(value, int):
            raise SettingsValidationError(f"{path} must be an integer")
        if value < minimum or value > maximum:
            raise SettingsValidationError(f"{path} must be between {minimum} and {maximum}")

    def boolean(value: Any, path: str) -> None:
        if not isinstance(value, bool):
            raise SettingsValidationError(f"{path} must be true or false")

    def text(value: Any, path: str, maximum: int, allow_controls: bool = False) -> None:
        if not isinstance(value, str):
            raise SettingsValidationError(f"{path} must be text")
        if len(value) > maximum:
            raise SettingsValidationError(f"{path} must be {maximum} characters or fewer")
        if not allow_controls and any(ord(char) < 32 for char in value):
            raise SettingsValidationError(f"{path} cannot contain control characters")

    camera = section(settings, "camera", "camera")
    resolution = section(camera, "resolution", "camera.resolution")
    integer(resolution.get("width"), "camera.resolution.width", 100, 4000)
    integer(resolution.get("height"), "camera.resolution.height", 100, 4000)
    number(camera.get("exposure_value"), "camera.exposure_value", -2, 2)
    number(camera.get("sharpness"), "camera.sharpness", 0, 10)
    if camera.get("autofocus_mode") not in {0, 1, 2}:
        raise SettingsValidationError("camera.autofocus_mode must be 0, 1, or 2")

    processing = section(settings, "processing", "processing")
    number(processing.get("saturation"), "processing.saturation", 0, 2)
    number(processing.get("brightness_factor"), "processing.brightness_factor", 0.1, 3)
    number(processing.get("color_factor"), "processing.color_factor", 0.1, 3)
    if processing.get("dithering_method") not in {"floyd_steinberg", "ordered"}:
        raise SettingsValidationError("processing.dithering_method is unsupported")
    if processing.get("bayer_size") not in {2, 4, 8}:
        raise SettingsValidationError("processing.bayer_size must be 2, 4, or 8")
    number(processing.get("threshold_scale"), "processing.threshold_scale", 0.1, 2)

    display = section(settings, "display", "display")
    boolean(display.get("auto_display"), "display.auto_display")
    number(display.get("display_timeout"), "display.display_timeout", 0, 3600)

    system = section(settings, "system", "system")
    integer(system.get("auto_refresh_interval"), "system.auto_refresh_interval", 5, 300)
    integer(system.get("auto_timeout_minutes"), "system.auto_timeout_minutes", 1, 60)
    boolean(system.get("auto_timeout_enabled"), "system.auto_timeout_enabled")
    integer(system.get("shutdown_warning_seconds", 60), "system.shutdown_warning_seconds", 0, 600)
    boolean(system.get("shutdown_buzzer_enabled", True), "system.shutdown_buzzer_enabled")
    integer(system.get("shutdown_buzzer_pin", 23), "system.shutdown_buzzer_pin", 0, 27)
    boolean(system.get("show_dashboard_qr_on_wifi_connect"), "system.show_dashboard_qr_on_wifi_connect")
    text(system.get("camera_name", ""), "system.camera_name", 80)

    exports = section(settings, "exports", "exports")
    boolean(exports.get("upscale_dithered_2x"), "exports.upscale_dithered_2x")

    extensions = section(settings, "extensions", "extensions")
    arena = section(extensions, "arena", "extensions.arena")
    boolean(arena.get("enabled"), "extensions.arena.enabled")
    text(arena.get("channel", ""), "extensions.arena.channel", 200)
    text(arena.get("access_token", ""), "extensions.arena.access_token", 4096)
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

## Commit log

2026-06-12 Initial public release
    Snapshot of the reFrame camera project for public release.
    [bezel.stl, enclosure.stl, lid.stl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]
2026-07-16 update checks + camera names
2026-07-17 fix: harden camera runtime state
    Allocate photo IDs monotonically, make monitor shutdown interruptible, and show the dashboard QR on Wi-Fi reconnects.
    [reframe.py]
2026-07-17 docs: refresh dashboard and setup guides
    Add the optimized dashboard screenshot and document updater installation, Wi-Fi QR behavior, and the required camera account.
2026-07-26 fix: python env quirks for new installs
    [dashboard_proxy.py]
